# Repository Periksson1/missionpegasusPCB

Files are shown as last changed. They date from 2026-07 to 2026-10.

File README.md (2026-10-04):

# Mission Pegasus

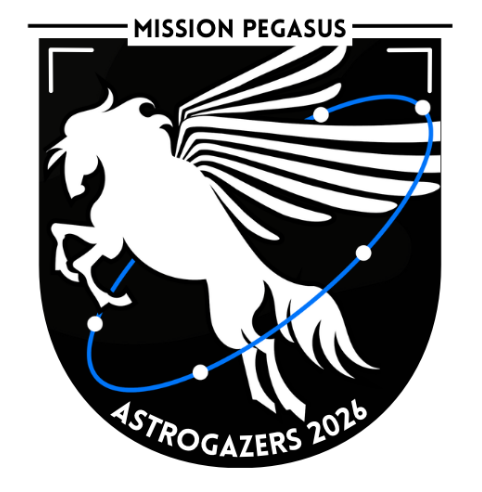
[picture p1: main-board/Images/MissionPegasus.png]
Mission Pegasus — Astrogazers 2026


PCB and mechanical design files for Mission Pegasus: a Raspberry Pi Zero carrier
and an AMS AS7265x spectral sensor board, designed to mate at 90°. The repository
includes schematics, PCB layouts, custom component libraries, mechanical CAD,
modal-analysis project files, and bills of materials.

## PDF schematics

Browse the current schematics without installing KiCad:

- [Main-board schematic (PDF)](output/pdf/main-board-schematic.pdf) - Raspberry Pi, stack interface, programming, and sensor connectors.
- [Sensor-board schematic (PDF)](output/pdf/sensor-board-schematic.pdf) - AS7265x sensors, flash, and board connector.

These are vector PDF exports of the current board schematics. Zoom in for pin
labels and component values. Regenerate the PDFs whenever the source schematics change.

## 3D CAD previews

These views are rendered from the KiCad PCB files and their associated 3D models.

### Main board

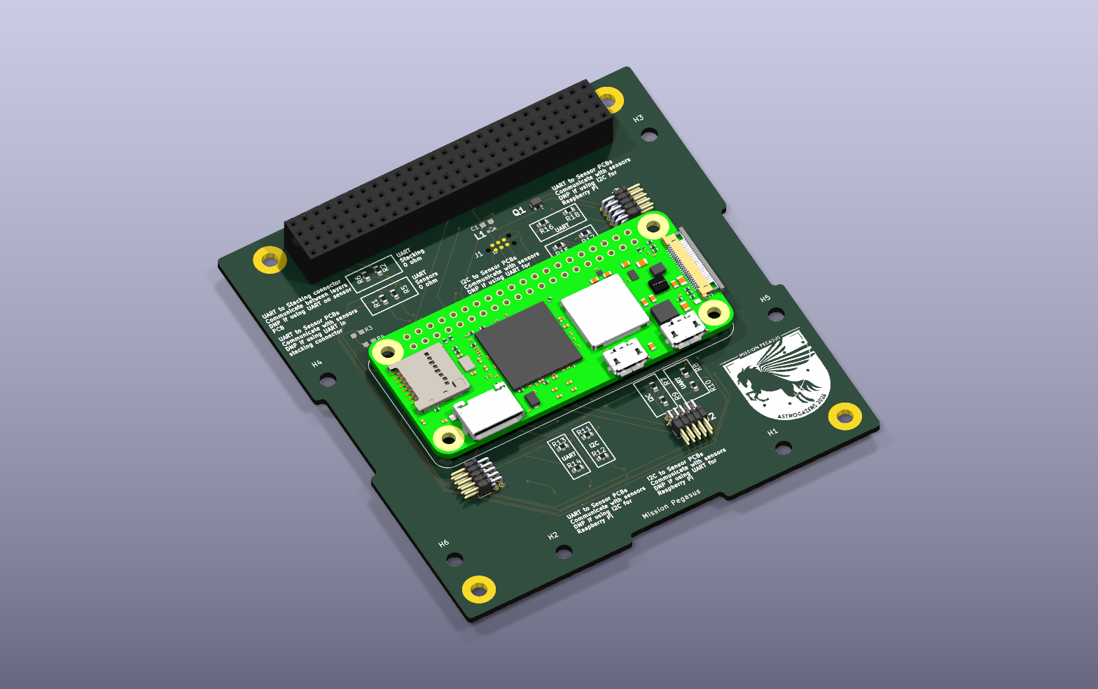
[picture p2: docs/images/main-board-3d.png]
Main-board 3D CAD view with Raspberry Pi Zero and stack connector


[Open the main-board project](main-board/Mission%20Pegasus.kicad_pro).

### Sensor board

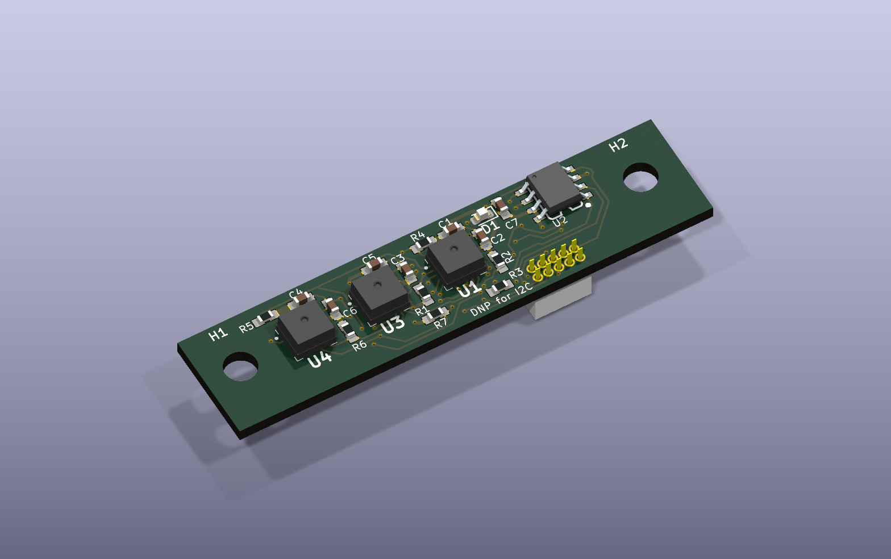
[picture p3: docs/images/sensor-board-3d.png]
Sensor-board 3D CAD view showing the spectral sensor components


[Open the sensor-board project](mezzanine-board/sensorPCB.kicad_pro).
For the mechanical assembly, see the [STEP export](CAD/PCBAssemblyFEA.stp)
and [Inventor CAD files](CAD/).

## Current design and status

The current design is on **[`main`](https://github.com/Periksson1/missionpegasusPCB/tree/main)**.
This is the default branch shown when you open the repository on GitHub.

Both boards have KiCad schematics and PCB layouts. CAD assemblies and an ANSYS
modal-analysis project are included. Manufacturing, assembly, electrical test,
and analysis pass/fail results are **not documented here yet**; the presence of
these files does not establish that the hardware has been validated.

## Getting started

1. Install **KiCad 10.0 or newer**. Both PCB files were saved with KiCad 10.0.
2. Clone the current design:

   ```sh
   git clone --branch main https://github.com/Periksson1/missionpegasusPCB.git
   cd missionpegasusPCB
   ```

3. Open `main-board/Mission Pegasus.kicad_pro` or
   `mezzanine-board/sensorPCB.kicad_pro` in KiCad's project manager.
4. Keep the project folders and their `libraries/` directories together. Custom
   library tables use `${KIPRJMOD}` paths; standard KiCad libraries are also needed.

For mechanical work, `.iam` and `.ipt` files are Autodesk Inventor assemblies and
parts. STEP (`.step` / `.stp`) exports are supplied for compatible CAD viewers.
`Analysis/ModalAnalysis.wbpj` is an ANSYS Workbench project; retain its adjacent
`ModalAnalysis_files/` directory. Exact Inventor and ANSYS application requirements
have not been documented.

## Boards

| Project | Description | Documentation |
|---|---|---|
| [Main board](main-board/Mission%20Pegasus.kicad_pro) | Raspberry Pi Zero carrier and stack interface | [Main-board README](main-board/README.md) |
| [Mezzanine board](mezzanine-board/sensorPCB.kicad_pro) | Spectral sensor daughterboard for the perpendicular assembly | [Mezzanine README](mezzanine-board/README.md) |

## Repository layout

| Path | Contents |
|---|---|
| `main-board/` | Main-board KiCad project, local libraries, documentation, BOMs, and CAD exports |
| `mezzanine-board/` | Sensor-board KiCad project, local libraries, BOMs, and CAD exports |
| `CAD/` | Mechanical assemblies, bracket parts, and assembly STEP export |
| `Analysis/` | ANSYS Workbench modal-analysis project and supporting files |
| `Combined BOM.xlsx` | Combined bill of materials |
| `Peter's Files/` | Additional copies of board projects, CAD, BOMs, and vendor software; use the top-level board folders for the documented workflow |
| `vendor/` | Third-party AMS dashboard software, firmware, and FTDI driver files |
| `MEZZANINE_INTERFACE.md` | Draft connector/interface planning notes with incomplete pin assignments |

The relationship and revision differences between `Peter's Files/` and the
top-level projects have not been reconciled in this documentation.

## BOMs and design references

- [Combined BOM](Combined%20BOM.xlsx)
- [Main-board BOM](main-board/Mission%20PegasusBOM.csv)
- [Sensor-board BOM](mezzanine-board/sensorPCBBOM.csv)
- [Component notes](main-board/docs/Components.docx) and [datasheets](main-board/docs/datasheets/)
- [Stack-interface schematic](main-board/StackInterface.kicad_sch)
- [Draft mezzanine interface](MEZZANINE_INTERFACE.md)
- [Mechanical assembly STEP export](CAD/PCBAssemblyFEA.stp)

BOMs and CAD exports are saved snapshots. Check them against the chosen board
revision before ordering parts or manufacturing. The interface document still
contains `TBD` pins; use the current schematics and verify connector numbering
and mechanical orientation before connecting hardware.

## Editing the designs

The main-board schematic contains cached versions of `AS72652`, `AS72653`, and
`RASPBERRY_PI_ZERO_2_W`. As noted in the [main-board documentation](main-board/README.md),
the corresponding library copies are older/incomplete. **Do not run
Tools → Update Symbols from Library on these parts** without first reconciling
the library definitions with the schematic.

When preparing a hardware revision, record its ERC/DRC results, fabrication
revision, assembly status, and test results alongside the design so readers can
distinguish design work from validated hardware.

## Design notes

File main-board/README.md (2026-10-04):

# Mission Pegasus main board

KiCad design for the Raspberry Pi Zero carrier and stack interface in the
Mission Pegasus two-board assembly.

[View the schematic PDF](../output/pdf/main-board-schematic.pdf).

## Opening the project

Use **KiCad 10.0 or newer** and open
[`Mission Pegasus.kicad_pro`](Mission%20Pegasus.kicad_pro).
See the [root README](../README.md) for cloning the current `main` branch.

## Files and references

| Path | Purpose |
|---|---|
| `Mission Pegasus.kicad_pro` | KiCad project settings |
| `Mission Pegasus.kicad_sch` | Root schematic |
| `Mission Pegasus.kicad_pcb` | PCB layout |
| `RPI0.kicad_sch` | Raspberry Pi Zero schematic sub-sheet |
| `StackInterface.kicad_sch` | Stack/GPIO interface sub-sheet |
| `fp-lib-table`, `sym-lib-table` | Project-local library registrations |
| `libraries/` | Custom footprints, symbols, and 3D models |
| `docs/` | Datasheets, component notes, ordering paperwork, and reference block diagram |
| `Mission PegasusBOM.csv` | Saved board BOM |
| `Images/` | Project artwork |
| `mainboard*.step`, `mainboard6/` | Mechanical exports and CAD files |

Custom library tables use `${KIPRJMOD}` paths. Keep the libraries with the
project and install the standard KiCad libraries. Third-party dashboard software,
firmware, and drivers are in [`../vendor/`](../vendor/).

## Interface and status

See the [stack schematic](StackInterface.kicad_sch) and
[draft mezzanine interface notes](../MEZZANINE_INTERFACE.md). The notes still have
incomplete pin assignments and must be checked against the current schematics.

Schematic and PCB design files are present. Manufacturing and electrical test
results are not documented. Check the [BOM](Mission%20PegasusBOM.csv) and mechanical
exports against the selected revision before using them for fabrication.

## Note on library symbols

The symbols cached in the schematics (`AS72652`, `AS72653`, and
`RASPBERRY_PI_ZERO_2_W`) are the authoritative, complete versions described by this
project's existing documentation. The library copies are older/incomplete.
**Do not run Tools → Update Symbols from Library on these parts** without first
reconciling the definitions; replacing them can break connectivity.

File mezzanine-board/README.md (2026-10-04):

# Mission Pegasus mezzanine sensor board

Spectral sensor daughterboard for the perpendicular Mission Pegasus assembly.
The KiCad project already contains a schematic and PCB layout.

[View the schematic PDF](../output/pdf/sensor-board-schematic.pdf).

## Opening the project

Use **KiCad 10.0 or newer** and open [`sensorPCB.kicad_pro`](sensorPCB.kicad_pro).
See the [root README](../README.md) for cloning the current `main` branch.
Keep the project's `libraries/` directory alongside the design files; custom
library registrations use `${KIPRJMOD}` paths. Standard KiCad libraries are also
needed.

## Files and references

| Path | Purpose |
|---|---|
| `sensorPCB.kicad_pro` | KiCad project settings |
| `sensorPCB.kicad_sch` | Sensor-board schematic |
| `sensorPCB.kicad_pcb` | Sensor-board PCB layout |
| `fp-lib-table`, `sym-lib-table` | Custom library registrations |
| `libraries/` | Custom symbols, footprints, and 3D models |
| `sensorPCBBOM.csv` | Saved sensor-board BOM |
| `sensorboard*.step` | Mechanical exports |
| `sensorboard2/`, `sensorboard3/`, `sensorboard5/` | CAD parts and assemblies |

## Mating interface

Review the [main-board stack schematic](../main-board/StackInterface.kicad_sch)
and both current board schematics when checking the connector pinout. The
[draft interface notes](../MEZZANINE_INTERFACE.md) contain incomplete assignments;
they are not a verified wiring specification.

Confirm pin-1 orientation, matching signal assignments, connector placement,
and clearance in the perpendicular assembly. Assembly CAD is in
[`../CAD/`](../CAD/).

## Design status

Schematic, PCB, BOM, and mechanical files are present. Manufacturing, assembly,
and electrical test results are not documented. The [BOM](sensorPCBBOM.csv) and
CAD exports should be checked against the chosen PCB revision before use.

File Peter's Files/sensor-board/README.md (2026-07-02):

# Mezzanine board (90°)

Daughterboard that mates **perpendicular** to the Mission Pegasus main board
via the shared 2x26 (2.54 mm) stack connector.

> Status: not started — create the KiCad project into this folder (see below).

## Creating the project

1. In KiCad: **File → New Project…**
2. Save it **inside this `mezzanine-board/` folder** (e.g. `Mezzanine.kicad_pro`).
   Keep "Create a new folder" **unchecked** so the files land here directly.
3. Custom parts go in the pre-made `libraries/` subfolders:
   - `libraries/footprints/` (`.pretty`)
   - `libraries/symbols/` (`.kicad_sym`)
   - `libraries/3dmodels/` (`.3dshapes`)
   Register them in this project's `fp-lib-table` / `sym-lib-table` using
   `${KIPRJMOD}/libraries/...` paths so the board stays self-contained.

## The 90° mating interface

- Use the **same connector part and pinout** as the main board's stack
  interface (see `../main-board/StackInterface.kicad_sch`). Pin 1 must meet
  pin 1.
- For the right-angle mate, typically one board carries a **right-angle**
  header and the other a vertical socket. Decide which side is which.
- Match the **connector position and board outline** so the boards align
  physically. Verify by exporting STEP from both boards and checking the
  perpendicular fit in a 3D view.

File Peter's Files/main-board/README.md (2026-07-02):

# Mission Pegasus PCB

KiCad design for the Mission Pegasus board — a Raspberry Pi Zero based
carrier with an AMS AS7265x spectral sensor front end.

## Opening the project

Open `Mission Pegasus.kicad_pro` in KiCad (10.0 or newer).

## Layout

```
Mission Pegasus.kicad_pro / .sch / .pcb   Main project (open this)
RPI0.kicad_sch                            Sub-sheet: Raspberry Pi Zero
StackInterface.kicad_sch                  Sub-sheet: stack / GPIO interface
fp-lib-table, sym-lib-table               Project-local library registrations

libraries/                                All custom parts libraries
├── footprints/   *.pretty                Footprint libraries
├── symbols/      *.kicad_sym             Symbol libraries
└── 3dmodels/     *.3dshapes              3D models (STEP)

docs/                                     Documentation & manufacturing
├── datasheets/                           AS7265x datasheets / app notes
├── Components.docx                       Component notes
├── Mission Pegasus.csv                   BOM
├── Order Request form.xlsx              Ordering paperwork
└── block_diagram.kicad_sch              Reference block diagram (not in build)

vendor/                                   Third-party tooling (reference only)
└── AS7265x DashBoard Software/           AMS dashboard app, firmware, FTDI driver
```

All library and 3D-model paths are project-relative (`${KIPRJMOD}`), so the
repo is self-contained — clone it anywhere and it opens without missing files.

## Note on library symbols

The symbols cached in the schematics (AS72652 / AS72653 / RASPBERRY_PI_ZERO_2_W)
are the authoritative, complete versions and match the PCB. The library copies
are older/incomplete. **Do not run _Tools → Update Symbols from Library_** on
these parts — it would pull the incomplete library version into the schematic
and break connectivity.

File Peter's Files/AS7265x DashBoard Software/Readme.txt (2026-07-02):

For AS7265x 

This folder consist of

          - FTDI Virtual COM Port Driver Setup exe file 
          - Dashboard Software - tcl Dashboard Installation file (DashBoard software AS7265x)
          - current AS7265 firmware - Complete 256kb and Update 56kb firmware bin file and AT-command list xlsx file

Note: - PC and Winbdws 32/64 Bit
              ActiveState TCL Run-Time Setup - TCL run time exe file for windows 32 or 64 bit (download from ActiveState TCL site) to run the Dashboard Software 

The AS7265x test system is tightly integrated with its companion firmware, which allows periodic enhancements and updates. Please download the latest version of the datasheet, which includes the current command set and features on the Spectral Sensing Product family page at https://ams.com/upload-center.
Also download User Guide.

User will have to create an account on ams.com (click login -> Create Account) to request the download SW data and relevent documents 

Please read forUser Guide in the documentation set. Then connect the hardware based on our instructions in User Guide  and run the test software.

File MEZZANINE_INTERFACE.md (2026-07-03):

# Mezzanine 90° Interface Specification

The single source of truth for the connector shared between the **main board**
and the **90° mezzanine board**. Edit this first; then make both boards match it.

## Connector

| Property | Value |
|---|---|
| Type | 2×20, 2.54 mm pitch, 40 positions |
| Mezzanine side | Molex **90152-2140** right-angle receptacle (makes the mezzanine stand vertical) |
| Main board side | Vertical 2×20 pin header (KiCad `Connector_PinHeader_2.54mm:PinHeader_2x20_P2.54mm_Vertical`) |
| Locations on main board | **3**, all populated, wired **in parallel** to the same nets (plug the mezzanine into any one) |
| Constraint | Only **one** mezzanine plugged at a time (parallel positions share nets) |

> Pin 1 on the main-board header must meet pin 1 on the mezzanine receptacle.
> Confirm the receptacle's pin-1 location and numbering direction against the
> Molex datasheet before finalizing the footprint.

## Pin assignment (fill this in)

Signals are TBD — assign from the "available signals" menu below based on what
the mezzanine needs. Power/ground pins are pre-suggested for signal integrity
(GND on corners + middle; keep power and its return adjacent).

| Pin | Signal | | Pin | Signal |
|----:|---|-|----:|---|
| 1 | GND *(key/orientation)* | | 2 | 5V_PERM |
| 3 | TBD | | 4 | 5V_PERM |
| 5 | TBD | | 6 | GND |
| 7 | TBD | | 8 | TBD |
| 9 | TBD | | 10 | TBD |
| 11 | TBD | | 12 | TBD |
| 13 | TBD | | 14 | TBD |
| 15 | TBD | | 16 | TBD |
| 17 | TBD | | 18 | TBD |
| 19 | TBD | | 20 | GND |
| 21 | GND | | 22 | TBD |
| 23 | TBD | | 24 | TBD |
| 25 | TBD | | 26 | TBD |
| 27 | TBD | | 28 | TBD |
| 29 | TBD | | 30 | TBD |
| 31 | TBD | | 32 | TBD |
| 33 | TBD | | 34 | TBD |
| 35 | TBD | | 36 | GND |
| 37 | TBD | | 38 | BATT |
| 39 | GND | | 40 | BATT |

## Available signals (from the main board stack, for reference)

Buses / signals present on the main board that the mezzanine could tap:

- **Power**: `5V_PERM`, `BATT`, `CHARGE`, `PWR_1`…`PWR_20` (each with an `ENA_PWR_n` enable)
- **CAN**: `CAN_A_H` / `CAN_A_L`, `CAN_B_H` / `CAN_B_L`
- **UART**: `UART_A_UP`/`UART_A_DN` … `UART_F_UP`/`UART_F_DN`
- **Deploy / RBF**: `RBF_A`, `RBF_B`, `DS_A`, `DS_B`
- **Ground**: `GND`

Full extracted stack pinout is in the git history of `main-board/` (netlist);
regenerate anytime with:
`kicad-cli sch export netlist --format kicadxml "main-board/Mission Pegasus.kicad_sch"`

## Build order

1. **This file** — lock the 40-pin assignment.
2. **Main board** — add 3× `PinHeader_2x20_P2.54mm_Vertical`, wire all three in
   parallel to the assigned nets, add mounting holes at each location.
3. **Mezzanine board** — place the Molex right-angle receptacle with the same
   pinout, design the board outline, add matching mounting holes.
4. **Mechanical check** — export STEP from both boards, confirm the perpendicular
   fit and that the 3 positions don't collide with other components.

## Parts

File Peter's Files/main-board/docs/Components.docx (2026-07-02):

Spectral sensors

AS72651-BLGT

https://www.mouser.co.uk/ProductDetail/ams-OSRAM/AS72651-BLGT?qs=YCa%2FAAYMW03SsE5ip4GyWw%3D%3D

AS72652-BLGM

https://www.mouser.co.uk/ProductDetail/ams-OSRAM/AS72652-BLGM?qs=byeeYqUIh0MwQKd6yzDQEA%3D%3D

AS72653-BLGM

https://www.mouser.co.uk/ProductDetail/ams-OSRAM/AS72653-BLGM?qs=byeeYqUIh0N5Q0CaJCwXCA%3D%3D

4MB Flash

https://www.mouser.co.uk/c/?q=AT25SF041

Diagram

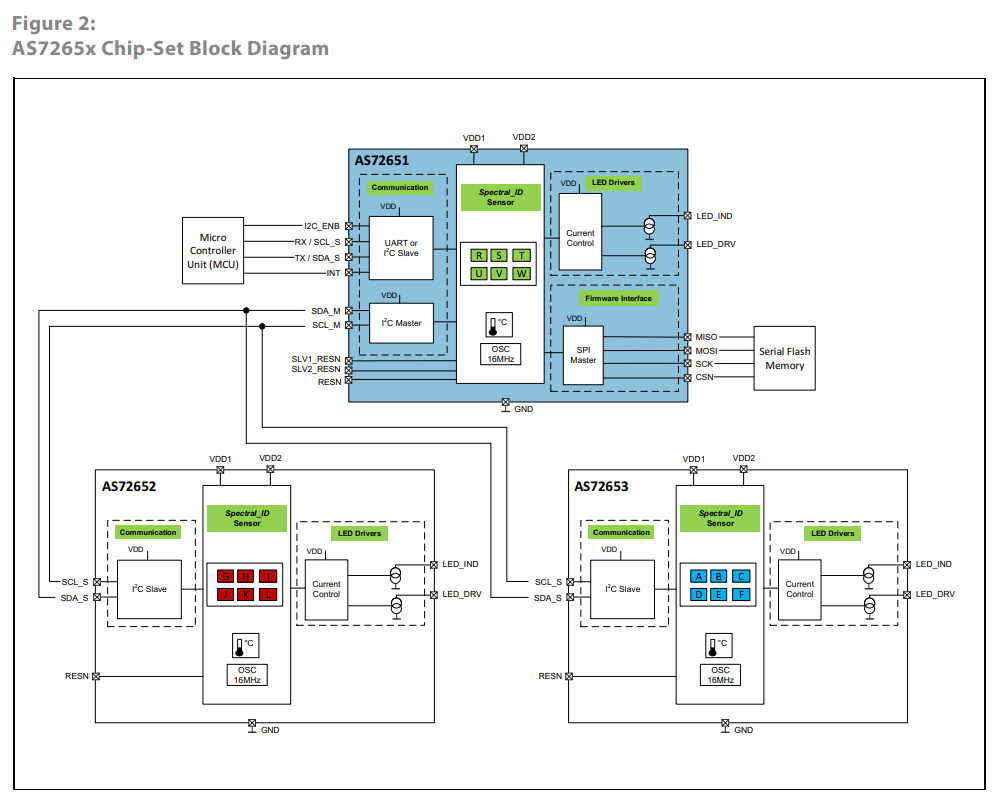
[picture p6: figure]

Design considerations

The AS72651 device needs a flash memory to store the firmware and the data. The flash memory should be at least 2-Mbits operating at SPI mode 0 with byte write supported.

The LED, D11 in the typical schematic, is recommended for debugging purpose. During AS72651 power up, D11 should be on for a short time and off. If D11 is blinking, it indicates there is an issue with accessing the flash memory content.

Schematic

file:///C:/Users/User/OneDrive%20-%20University%20of%20Bath/Mission%20Pegasus/Sparkfun/AS7265x%20Schematic%20Generation_2.pdf

Firmware

Connectors

PC104 layers

Samtec ESQ-126-39-G-D

https://www.mouser.co.uk/ProductDetail/Samtec/ESQ-126-39-G-D?qs=Cqqh%252BS766wm7W672HSOlSA%3D%3D

Raspberry pi to main board

https://www.mouser.co.uk/ProductDetail/SchmartBoard/920-0135-01?qs=WBUF01kN13lvFiBwxduHPw%3D%3D

Spark fun Github

https://github.com/sparkfun/Qwiic_Spectral_Sensor_AS7265x

Questions

VDD1 VDD1

INT and RST help, why not on the qwik connect

All on one board?

No LEDs

RST ADDR

Trust schematic or datasheet

Get MOUSR numbers for 10 boards

Sensors on opposite sides

Pi zero, boards

Farnell

Raspberry Pis in space

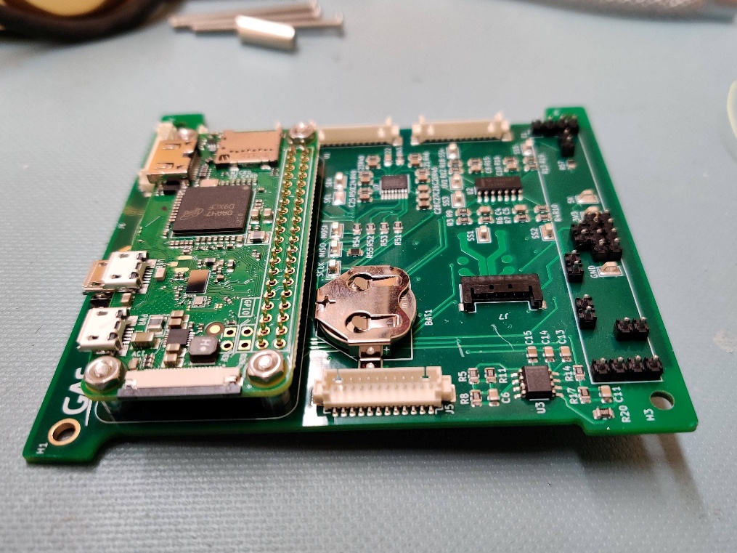
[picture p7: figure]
GASPACS Electrical Board

https://nepp.nasa.gov/docs/papers/2021-Guertin-Raspberry-Pi-Guideline-CL-21-5641.pdf

Watchdog

DFRobot Beetle Board

Software

https://github.com/SmallSatGasTeam/CubeWorks

2 x20 pins connection

https://thepihut.com/products/break-away-0-1-2x20-pin-strip-dual-male-header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

https://www.mouser.co.uk/ProductDetail/SchmartBoard/920-0199-01?qs=5aG0NVq1C4wO2QQoWinwcA%3D%3D

Board to board

https://www.mouser.co.uk/ProductDetail/Amphenol-FCI/68021-120HLF?qs=QKvFUfBIyQLKTXbLGClQCQ%3D%3D

https://www.mouser.co.uk/ProductDetail/Molex/10-88-3201?qs=yq6dHiFsY%2FwBE5jk1c6zoQ%3D%3D

PCB Receptacle, Board-to-Board, 2.54 mm, 2 Rows, 40 Contacts, Female Receptacle

https://uk.farnell.com/molex/90152-2140/conn-r-a-rcpt-40pos-2row-2-54mm/dp/3865288

https://www.mouser.co.uk/ProductDetail/Molex/503376-4010?qs=6kT3pPPHxnUcJRrksBOx%2Fg%3D%3D

https://www.mouser.co.uk/ProductDetail/Molex/70247-4051?qs=L7RdmAxh%252BcMhqlOlB5RHog%3D%3D

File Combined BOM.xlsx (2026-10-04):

Mission Pegasus BOM
Sensor PCB
Reference | Catalogue Number | Qty | Value | Description | Unit Price | Supplier | Link | Footprint | Datasheet
C1,C3,C4 | 581-0603YC104K4T4A | 3 | 100nF | Capacitor | 0.027 |  | https://www.mouser.co.uk/ProductDetail/KYOCERA-AVX/0603YC104K4T4A?qs=Cej1j9ztgjEkPqVJkA4Bng%3D%3D | SparkfunLibrary:0603
C2,C5,C6 | 06033D105KAT4A | 3 | 1 uF | Capacitor | 0.074 |  | https://www.mouser.co.uk/ProductDetail/KYOCERA-AVX/06033D105KAT4A | SparkfunLibrary:0603
C7 | 06033D105KAT4A | 1 | 1uF | Capacitor | 0.074 |  | https://www.mouser.co.uk/ProductDetail/KYOCERA-AVX/06033D105KAT4A | SparkfunLibrary:0603
D1 | 327-FR1101C2005MTR | 1 | GREEN | LED | £0.18 | Mouser | https://www.mouser.co.uk/en/ProductDetail/Stanley-Electric/FR1101C-2005-M-TR | LED_SMD:LED_0603_1608Metric
J1 | 200-SFMC10501LD | 1 | SFMC-105-01-L-D | 10 pin header | £1.58 | Mouser | https://www.mouser.co.uk/en/ProductDetail/Samtec/SFMC-105-01-L-D?qs=PB6%2FjmICvI2ISwddtR74VA%3D%3D | SamacSys_Parts:SFMC-105-XX-YY-D | http://suddendocs.samtec.com/prints/sfmc-1xx-xx-xx-d-xx-mkt.pdf
R1,R2,R4,R5 | 71-CRCW060310K0FKEI | 4 | 10k | 10 k ohm resistor | 0.047 | Mouser | https://www.mouser.co.uk/ProductDetail/Vishay/CRCW060310K0FKEI?qs=3qWEzBg5KnKofE%252B8acPBRA%3D%3D | SparkfunLibrary:0603
R3 | 603-RC0603FR-100RL | 1 | 0R | 0 ohm resistors | £0.01 | Mouser | https://www.mouser.co.uk/en/ProductDetail/YAGEO/RC0603FR-100RL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 | SparkfunLibrary:0603
R6,R7 | 71-CRCW0603-2.2K-E3 | 2 | 2.2k | 2.2 k Ohm resistor | 0.015 | Mouser | https://www.mouser.co.uk/en/ProductDetail/Vishay/CRCW06032K20FKEA?qs=wckIcdUuIXiMEbhHncbunA%3D%3D | SparkfunLibrary:0603
U1 | 985-AS72651-BLGM | 1 | AS72651 | Sensor | 7.23 | Mouser | https://www.mouser.co.uk/ProductDetail/ams-OSRAM/AS72651-BLGM?qs=byeeYqUIh0PtfXPN2yhDCA%3D%3D | SamacSys_Parts:AS72651BLGT | https://ams.com/documents/20143/36005/AS7265x_DS000612_1-00.pdf/08051c8a-a7f6-6231-7993-2d3fe0bf38b8
U2 | 988-AT25SF041BSSHDB | 1 | 4MB Flash | 4mb Flash | £0.48 | Mouser | https://www.mouser.co.uk/en/ProductDetail/Renesas-Dialog/AT25SF041B-SSHD-B?qs=IS%252B4QmGtzzoAv7Cb4U2tFA%3D%3D | SparkfunLibrary:4MbFlash
U3 | 985-AS72652-BLGM | 1 | AS72652 | Sensor | 7.23 | Mouser | https://www.mouser.co.uk/ProductDetail/ams-OSRAM/AS72652-BLGM?qs=byeeYqUIh0MwQKd6yzDQEA%3D%3D | SamacSys_Parts:AS72651BLGT
U4 | 985-AS72653-BLGM | 1 | AS72653 | Sensor | 7.23 | Mouser | https://www.mouser.co.uk/ProductDetail/ams-OSRAM/AS72653-BLGM?qs=byeeYqUIh0N5Q0CaJCwXCA%3D%3D | SamacSys_Parts:AS72651BLGT
Main Board
Reference | Catalogue Number | Qty | Value |  |  |  |  | Footprint | Datasheet
C1 | 581-0603YC104K4T4A | 1 | 100nF | Capacitor | 0.027 |  | https://www.mouser.co.uk/ProductDetail/KYOCERA-AVX/0603YC104K4T4A?qs=Cej1j9ztgjEkPqVJkA4Bng%3D%3D | SparkfunLibrary:0603
H7,H8 | 06033D105KAT4A | 2 | PC/104 Connector |  |  |  |  | Connector_PinSocket_2.54mm:PinSocket_2x26_P2.54mm_Vertical
J2,J3,J4 | FTSH-105-04-L-D-RA | 3 | FTSH-105-04-L-D-RA | Right angle connector | £1.44 | Digikey | https://www.digikey.co.uk/en/products/detail/samtec-inc/FTSH-105-04-L-D-RA/6678181 | SamacSys_Parts:FTSH-105-XX-YYY-D-RA | http://suddendocs.samtec.com/prints/ftsh-1xx-xx-xxx-dv-xxx-xxx-mkt.pdf
L1 | 710-7427927161 | 1 | 60R/250mA | Ferrite beads | 0.137 | Mouser | https://www.mouser.co.uk/en/ProductDetail/Wurth-Elektronik/7427927161?qs=%252B97ACBfLqz8R%252B1ZKS2FUPA%3D%3D | SamacSys_Parts:0402
Q1 | 755-DTC113ZEBTL | 1 | DTC113Z | Transistor | 0.107 | Mouser | https://www.mouser.co.uk/ProductDetail/ROHM-Semiconductor/DTC113ZEBTL?qs=qSfuJ%252Bfl%2Fd4AkBOHinnQ0A%3D%3D | SamacSys_Parts:DTC113ZUA
R1,R2,R5,R6,R7,R8,R9,R10,R11,R12,R13,R14,R15,R16,R17,R18 | 603-RC0603FR-100RL | 16 | 0R | 0 ohm resistors | £0.01 | Mouser | https://www.mouser.co.uk/en/ProductDetail/YAGEO/RC0603FR-100RL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 | Resistor_SMD:R_0603_1608Metric
R3,R4 | 71-CRCW0603-2.2K-E3 | 2 | 2.2k | 2.2 k Ohm resistor | 0.015 | Mouser | https://www.mouser.co.uk/en/ProductDetail/Vishay/CRCW06032K20FKEA?qs=wckIcdUuIXiMEbhHncbunA%3D%3D | SparkfunLibrary:0603
U1 |  | 1 | RASPBERRY_PI_ZERO_2_W |  |  |  |  | RPIZERO:RASPBERRYPI-ZERO_RPI-ZERO
Mounting
Catalogue Number | Qty | Description | Supplier | Link
36-615-ND | 2 | Angle bracket | Digikey | https://www.digikey.co.uk/en/products/detail/keystone-electronics/615/316537
855-R25-3000302 | 4 | Standoffs | Mouser | https://www.mouser.co.uk/en/ProductDetail/Harwin/R25-3000302?qs=vF78I%252BjhbY82jhRkZ%252BKjhQ%3D%3D
485-2222 | 1 | GPIO 2x20 Female Header 2.54mm pitch | Mouser | https://www.mouser.co.uk/en/ProductDetail/Adafruit/2222?qs=GURawfaeGuDZD0rNtWpsaQ%3D%3D
Flash
Catalogue Number | Qty | Description | Supplier | Link
TC2030-IDC-NL | 1 | Flash connector | Tag-Connect | https://www.tag-connect.com/product/tc2030-idc-nl

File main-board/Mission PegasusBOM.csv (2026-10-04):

Reference | Qty | Value | DNP | Exclude from BOM | Exclude from Board | Footprint | Datasheet | MANUFACTURER | Price
C1 | 1 | 100nF |  |  |  | SparkfunLibrary:0603
H7,H8 | 2 | PC/104 Connector |  |  |  | Connector_PinSocket_2.54mm:PinSocket_2x26_P2.54mm_Vertical
J2,J3,J4 | 3 | FTSH-105-04-L-D-RA |  |  |  | SamacSys_Parts:FTSH-105-XX-YYY-D-RA | http://suddendocs.samtec.com/prints/ftsh-1xx-xx-xxx-dv-xxx-xxx-mkt.pdf
L1 | 1 | 60R/250mA |  |  |  | SamacSys_Parts:0402
Q1 | 1 | DTC113Z |  |  |  | SamacSys_Parts:DTC113ZUA
R1,R2,R5,R6,R7,R8,R9,R10,R11,R12,R13,R14,R15,R16,R17,R18 | 16 | 0R |  |  |  | Resistor_SMD:R_0603_1608Metric
R3,R4 | 2 | 2.2k |  |  |  | SparkfunLibrary:0603
U1 | 1 | RASPBERRY_PI_ZERO_2_W |  |  |  | RPIZERO:RASPBERRYPI-ZERO_RPI-ZERO |  | Raspberry Pi | None

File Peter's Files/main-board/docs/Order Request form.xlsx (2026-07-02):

ORDER REQUEST FORM
To: | Finance |  |  |  | Requisition Number
From: |  |  |  |  | PO Number
Department:
Supplier Name: |  |  |  | Project Code:
Supplier Address: |  |  |  |  | Type of Purchase | Please indicate
 |  |  |  |  | Lab Equipment
 |  |  |  |  | Lab consumables
Telephone: |  |  |  |  | IT
Email: |  |  |  |  | Other
Quote number:
PLEASE SEND COMPLETED FORM TO fac-eng-finance@bath.ac.uk
 | Quantity | Catalogue Number | Description of Goods |  |  | Unit Price | Total Price | Supplier | Link
1 | 1 | TC2030-IDC-NL | Debugging Connector |  |  | £26.46 | 26.46 | Tag-Connect | https://www.tag-connect.com/product/tc2030-idc-nl
2 | 10 | 985-AS72651-BLGM | Sensor |  |  | 7.23 | 72.3 | Mouser | https://www.mouser.co.uk/ProductDetail/ams-OSRAM/AS72651-BLGM?qs=byeeYqUIh0PtfXPN2yhDCA%3D%3D
3 | 10 | 985-AS72652-BLGM | Sensor |  |  | 7.23 | 72.3 | Mouser | https://www.mouser.co.uk/ProductDetail/ams-OSRAM/AS72652-BLGM?qs=byeeYqUIh0MwQKd6yzDQEA%3D%3D
4 | 10 | 985-AS72653-BLGM | Sensor |  |  | 7.23 | 72.3 | Mouser | https://www.mouser.co.uk/ProductDetail/ams-OSRAM/AS72653-BLGM?qs=byeeYqUIh0N5Q0CaJCwXCA%3D%3D
5 | 60 | 581-0603YC104K4T4A | 0.1 uF Capacitor |  |  | 0.027 | 1.62 | Mouser | https://www.mouser.co.uk/ProductDetail/KYOCERA-AVX/0603YC104K4T4A?qs=Cej1j9ztgjEkPqVJkA4Bng%3D%3D
6 | 60 | 581-06033D105KAT4A | 1 uF Capacitor |  |  | 0.074 | 4.44 | Mouser | https://www.mouser.co.uk/ProductDetail/KYOCERA-AVX/06033D105KAT4A
7 | 10 | 710-7427927161 | Ferrite beads |  |  | 0.137 | 1.37 | Mouser | https://www.mouser.co.uk/ProductDetail/Wurth-Elektronik/7427927161?qs=%252B97ACBfLqz8R%252B1ZKS2FUPA%3D%3D
8 | 10 | 755-DTC113ZEBTL | Transistor |  |  | 0.107 | 1.07 | Mouser | https://www.mouser.co.uk/ProductDetail/ROHM-Semiconductor/DTC113ZEBTL?qs=qSfuJ%252Bfl%2Fd4AkBOHinnQ0A%3D%3D
9 | 80 | 71-CRCW0603-2.2K-E3 | Resistor |  |  | 0.015 | 1.2 | Mouser | https://www.mouser.co.uk/ProductDetail/Vishay/CRCW06032K20FKEA?qs=wckIcdUuIXiMEbhHncbunA%3D%3D
10 | 60 | 71-CRCW060310K0FKEI | Resistor |  |  | 0.047 | 2.82 | Mouser | https://www.mouser.co.uk/ProductDetail/Vishay/CRCW060310K0FKEI?qs=3qWEzBg5KnKofE%252B8acPBRA%3D%3D
 |  |  |  |  |  | Delivery:
 |  |  |  |  |  | Subtotal: | 255.88
 |  |  |  |  |  | 20% VAT: | 51.18
 |  |  |  |  |  | Total: | 307.06
Additional Forms - Have you attached?
£2000-£9999 |  | 3 Competative quotes or 1 quote and justification for only seeking one
£10,000- £24,999 |  | BID Evaluation Document (BED) https://www.bath.ac.uk/publications/bid-evaluation-document/ or Single Action Waiver (SAW) https://www.bath.ac.uk/publications/single-action-waiver/
£25,000+ |  | Contact Procurement https://www.bath.ac.uk/teams/procurement-team/

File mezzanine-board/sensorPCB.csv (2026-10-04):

Reference | Qty | Value | DNP | Exclude from BOM | Exclude from Board | Footprint | Datasheet
C1,C3,C4 | 3 | 100nF |  |  |  | SparkfunLibrary:0603
C2,C5,C6 | 3 | 1 uF |  |  |  | SparkfunLibrary:0603
C7 | 1 | 1uF |  |  |  | SparkfunLibrary:0603
D1 | 1 | GREEN |  |  |  | LED_SMD:LED_0603_1608Metric
J1 | 1 | SFMC-105-01-L-D |  |  |  | SamacSys_Parts:SFMC-105-XX-YY-D | http://suddendocs.samtec.com/prints/sfmc-1xx-xx-xx-d-xx-mkt.pdf
R1,R2,R4,R5 | 4 | 10k |  |  |  | SparkfunLibrary:0603
R3 | 1 | 0R |  |  |  | SparkfunLibrary:0603
R6,R7 | 2 | 2k2 |  |  |  | SparkfunLibrary:0603
U1 | 1 | AS72651 |  |  |  | SamacSys_Parts:AS72651BLGT | https://ams.com/documents/20143/36005/AS7265x_DS000612_1-00.pdf/08051c8a-a7f6-6231-7993-2d3fe0bf38b8
U2 | 1 | 4MB Flash |  |  |  | SparkfunLibrary:4MbFlash
U3 | 1 | AS72652 |  |  |  | SamacSys_Parts:AS72651BLGT
U4 | 1 | AS72653 |  |  |  | SamacSys_Parts:AS72651BLGT

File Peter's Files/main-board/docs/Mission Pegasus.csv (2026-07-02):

Reference | Qty | Value | DNP | Exclude from BOM | Exclude from Board | Footprint | Datasheet | MANUFACTURER | Price
C1,C3,C5,C8 | 4 | 100nF |  |  |  | SparkfunLibrary:0603
C2,C4,C6 | 3 | 1 uF |  |  |  | SparkfunLibrary:0603
C7 | 1 | 1uF |  |  |  | SparkfunLibrary:0603
D1 | 1 | GREEN
H1,H2 | 2 | PC/104 Connector |  |  |  | Connector_PinSocket_2.54mm:PinSocket_2x26_P2.54mm_Vertical
L1 | 1 | 60R/250mA |  |  |  | SamacSys_Parts:0402
Q1 | 1 | DTC113Z |  |  |  | SamacSys_Parts:DTC113ZUA
R1,R2 | 2 | 2.2k |  |  |  | SparkfunLibrary:0603
R3,R6,R7,R8 | 4 | 10k |  |  |  | SparkfunLibrary:0603
R5 | 1 | 0R |  |  |  | SparkfunLibrary:0603
R9,R10 | 2 | 2k2 |  |  |  | SparkfunLibrary:0603
TP1,TP2,TP3 | 3 | TestPoint |  |  |  | TestPoint:TestPoint_Pad_D1.0mm
U2 | 1 | 4MB Flash |  |  |  | SparkfunLibrary:4MbFlash
U3 | 1 | AS72652 |  |  |  | SparkfunLibrary:AS72651
U4 | 1 | AS72653 |  |  |  | SparkfunLibrary:AS72651
U6 | 1 | AS72651 |  |  |  | Package_LGA:AMS_LGA-20_4.7x4.5mm_P0.65mm | https://ams.com/documents/20143/36005/AS7265x_DS000612_1-00.pdf/08051c8a-a7f6-6231-7993-2d3fe0bf38b8
U7 | 1 | RASPBERRY_PI_ZERO_2_W |  |  |  | RPIZERO:RASPBERRYPI-ZERO_RPI-ZERO |  | Raspberry Pi | None

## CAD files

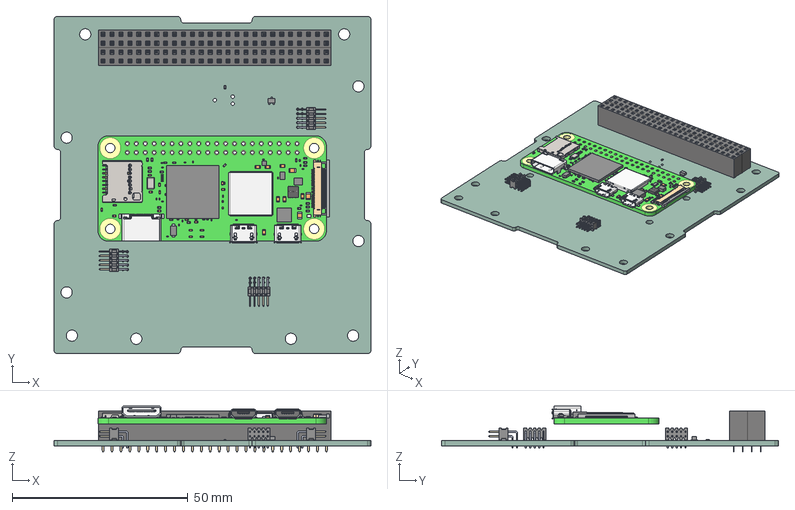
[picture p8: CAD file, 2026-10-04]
main-board/mainboard2.step
90.2 x 95.9 x 13.0 mm
Pins
PCB, Raspberry Pi Zero 2 W
RP3A0-AU 2105 201221C, Raspberry Pi Zero 2 W
MicroUSB Port, Raspberry Pi Zero 2 W x 2
SD Card Slot, Raspberry Pi Zero 2 W
Wireless Module Cover, Raspberry Pi Zero 2 W
Crystal Resonator, Raspberry Pi Zero 2 W
LED, Raspberry Pi Zero 2 W
Diode, Schottky, Raspberry Pi Zero 2 W
54548-2271, 22 Pin FPC Connector, Raspberry Pi Zero 2 W
Mini HDMI Receptacle Port, Raspberry Pi Zero 2 W
PAM2306AYPKE, Switching Voltage Regulators Dual PWM Step-Down 40uA 1A 1.5MHz, Raspberry Pi Zero 2 W
RT9081A-1BGQZA, Fixed LDO Voltage Regulator, 0.8V-5.5Vin, 140mV drop, 1.25Vout, 0.5Aout, Raspberry Pi Zero 2 W_default
RT8088AWSC, IC Reg Buck Prog 3A Sync 15WLCSP, Raspberry Pi Zero 2 W_default
SMD Inductor, Configurable, Raspberry Pi Zero 2 W_L1
SMD Inductor, Configurable, Raspberry Pi Zero 2 W_L2
SMD Capacitor, Configurable, Raspberry Pi Zero 2 W_C1 x 3
SMD Capacitor, Configurable, Raspberry Pi Zero 2 W_C3 x 7
SMD Capacitor, Configurable, Raspberry Pi Zero 2 W_C2 x 31
SMD Capacitor, Configurable, Raspberry Pi Zero 2 W_C10 x 15
SMD Resistor, Configurable, Raspberry Pi Zero 2 W_R1 x 20
SMD Resistor, Configurable, Raspberry Pi Zero 2 W_R12
Lötende x 2
PinSocket_2x26_P2.54mm_Vertical x 2
Mission Pegasus_PCB

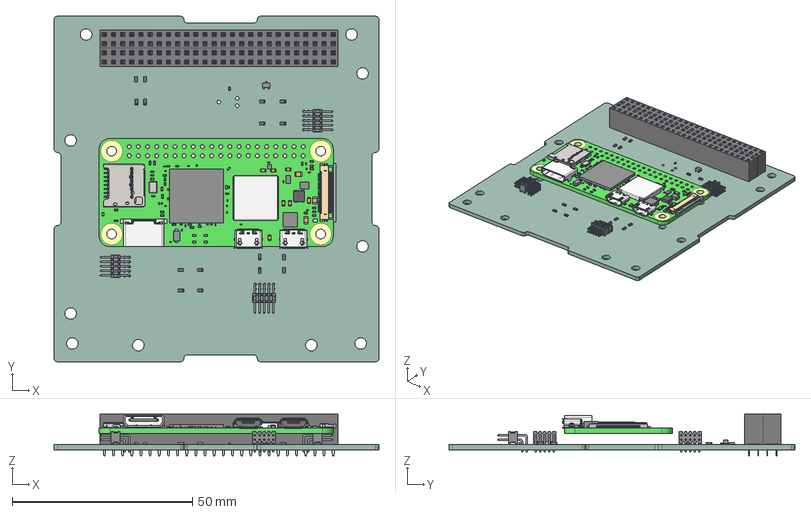
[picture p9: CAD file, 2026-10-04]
Peter's Files/main-board/mainboardCAD/mainboard6.step
90.2 x 95.9 x 11.6 mm
R_0603_1608Metric x 16
Pins
PCB, Raspberry Pi Zero 2 W
RP3A0-AU 2105 201221C, Raspberry Pi Zero 2 W
MicroUSB Port, Raspberry Pi Zero 2 W x 2
SD Card Slot, Raspberry Pi Zero 2 W
Wireless Module Cover, Raspberry Pi Zero 2 W
Crystal Resonator, Raspberry Pi Zero 2 W
LED, Raspberry Pi Zero 2 W
Diode, Schottky, Raspberry Pi Zero 2 W
54548-2271, 22 Pin FPC Connector, Raspberry Pi Zero 2 W
Mini HDMI Receptacle Port, Raspberry Pi Zero 2 W
PAM2306AYPKE, Switching Voltage Regulators Dual PWM Step-Down 40uA 1A 1.5MHz, Raspberry Pi Zero 2 W
RT9081A-1BGQZA, Fixed LDO Voltage Regulator, 0.8V-5.5Vin, 140mV drop, 1.25Vout, 0.5Aout, Raspberry Pi Zero 2 W_default
RT8088AWSC, IC Reg Buck Prog 3A Sync 15WLCSP, Raspberry Pi Zero 2 W_default
SMD Inductor, Configurable, Raspberry Pi Zero 2 W_L1
SMD Inductor, Configurable, Raspberry Pi Zero 2 W_L2
SMD Capacitor, Configurable, Raspberry Pi Zero 2 W_C1 x 3
SMD Capacitor, Configurable, Raspberry Pi Zero 2 W_C3 x 7
SMD Capacitor, Configurable, Raspberry Pi Zero 2 W_C2 x 31
SMD Capacitor, Configurable, Raspberry Pi Zero 2 W_C10 x 15
SMD Resistor, Configurable, Raspberry Pi Zero 2 W_R1 x 20
SMD Resistor, Configurable, Raspberry Pi Zero 2 W_R12
Lötende x 2
PinSocket_2x26_P2.54mm_Vertical x 2
Mission Pegasus_PCB

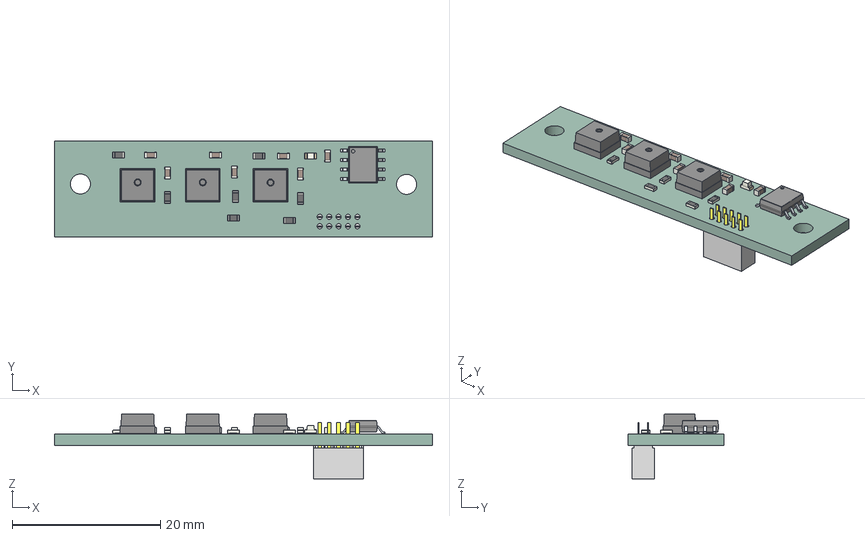
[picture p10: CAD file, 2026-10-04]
mezzanine-board/sensorboard3.step
51.0 x 13.0 x 8.73 mm
C_0603_1608Metric x 7
AS72651-BLGT x 3
R_0603_1608Metric x 7
LED_0603_1608Metric
PinsArrayLR
SFMC-105-01_socket
C-05-01_spins
sensorPCB_PCB

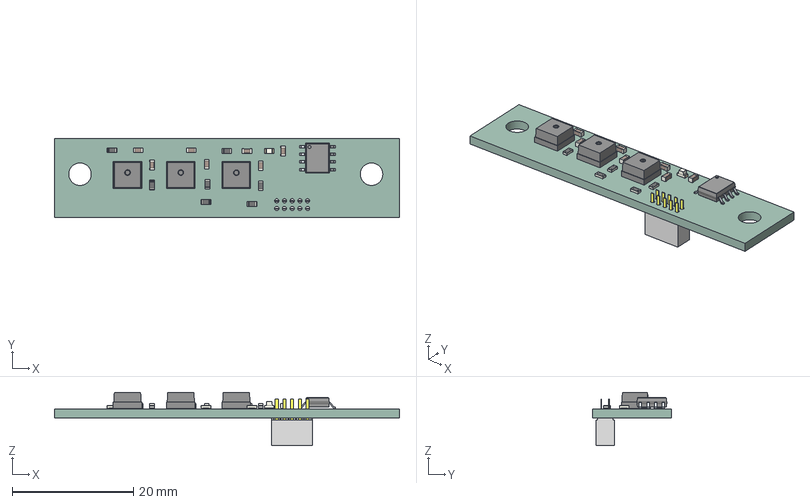
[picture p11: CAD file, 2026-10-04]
Peter's Files/sensor-board/sensorboardCAD/sensorboard5.step
56.8 x 13.0 x 8.73 mm
C_0603_1608Metric x 7
AS72651-BLGT x 3
R_0603_1608Metric x 7
LED_0603_1608Metric
PinsArrayLR
SFMC-105-01_socket
C-05-01_spins
sensorPCB_PCB

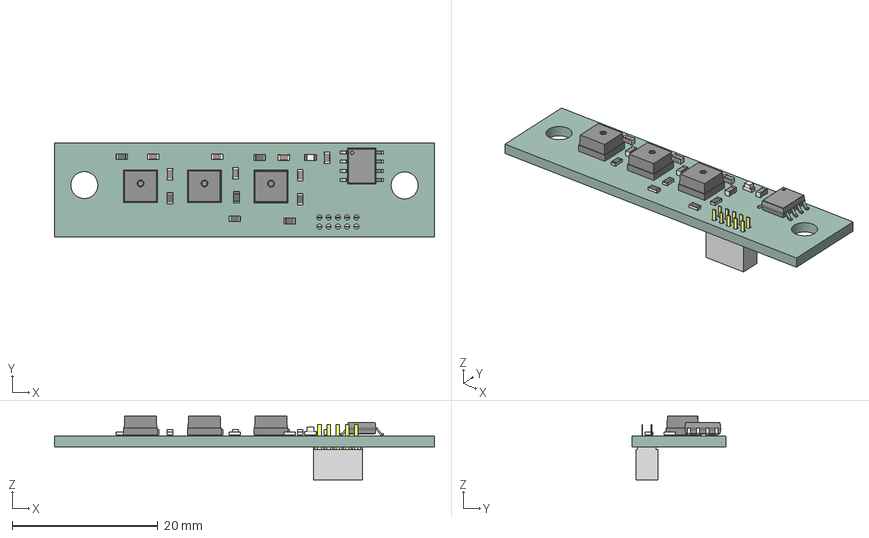
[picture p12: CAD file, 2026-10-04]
mezzanine-board/sensorboard4.step
52.2 x 13.0 x 8.73 mm
C_0603_1608Metric x 7
AS72651-BLGT x 3
R_0603_1608Metric x 7
LED_0603_1608Metric
PinsArrayLR
SFMC-105-01_socket
C-05-01_spins
sensorPCB_PCB

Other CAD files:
main-board/mainboard.step
main-board/mainboard4.step
main-board/mainboard5.step
mezzanine-board/sensorboard2.step
main-board/sensorboard5.step
mezzanine-board/sensorboard.step
CAD/615Bracket.ipt
CAD/OldVersions/PCBAssembly.0006.iam
CAD/OldVersions/PCBAssemblyFEA.0001.iam
CAD/PCBAssembly.iam
CAD/PCBAssemblyFEA.iam
Peter's Files/CAD/615Bracket.ipt
Peter's Files/CAD/OldVersions/PCBAssembly.0006.iam
Peter's Files/CAD/OldVersions/PCBAssemblyFEA.0001.iam
Peter's Files/CAD/PCBAssembly.iam
Peter's Files/CAD/PCBAssemblyFEA.iam
Peter's Files/CAD/PCBboard.ipt
Peter's Files/main-board/mainboardCAD/mainboard6.ipt
Peter's Files/sensor-board/sensorboardCAD/sensorboard5.ipt
main-board/mainboard/10.ipt
main-board/mainboard/54548-2271, 22 Pin FPC Connector, Raspberry Pi Zero 2 W.ipt
main-board/mainboard/7427927161.iam
main-board/mainboard/74279273.ipt
main-board/mainboard/ASSEMBLY.iam
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

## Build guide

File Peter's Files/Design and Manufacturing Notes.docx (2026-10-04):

Design and Manufacturing

Project aim

Create a prototype board for the school to implement into a cubesat. The aim was to create a single board which combines the Sparkfun Triad Spectoscopy Sensor (https://www.sparkfun.com/sparkfun-triad-spectroscopy-sensor-as7265x-qwiic.html#content-documentation) with a Raspberry Pi 0 2w.

This part is currently out of stock, and the sensors are scheduled for obsolescence.

Design considerations

The first step was to recreate the circuit necessary for the chips. An important thing to note is that the Sparkfun circuit is out of date as it uses the old version of the firmware.

Use the latest datasheet which can be found here (https://ams-osram.com/products/sensor-solutions/ambient-light-color-spectral-proximity-sensors/ams-as7265x-smart-spectral-sensor)

The firmware changes around some of the pins.

The main board was aimed to be designed to the librecube standards (https://librecube.gitlab.io/)

This set the physical dimensions of the board and a limit on the height of components attached to it.

Early in the design phase it was decided to split the circuit into two boards.

One main board with a perpendicular smaller board attached with right angled connectors.

This was done due to uncertainty as to where the board would be placed in the cubesat. If the sensors were placed directly onto s typical cubesat board it would be pointing directly at another board (unless it was on the top layer which was not guaranteed.

The sensor board was initially designed to not exceed the height of 8.76 mm. This was achieved after some difficult routing but due to the height of the right-angled connector, it would not have been possible to mount it to the board to the mainboard.

The sensor board was redesigned to have a height of 12mm which was much easier to route and remained between the 16mm spacing between boards (assuming nothing is placed underneath the PCB above it.

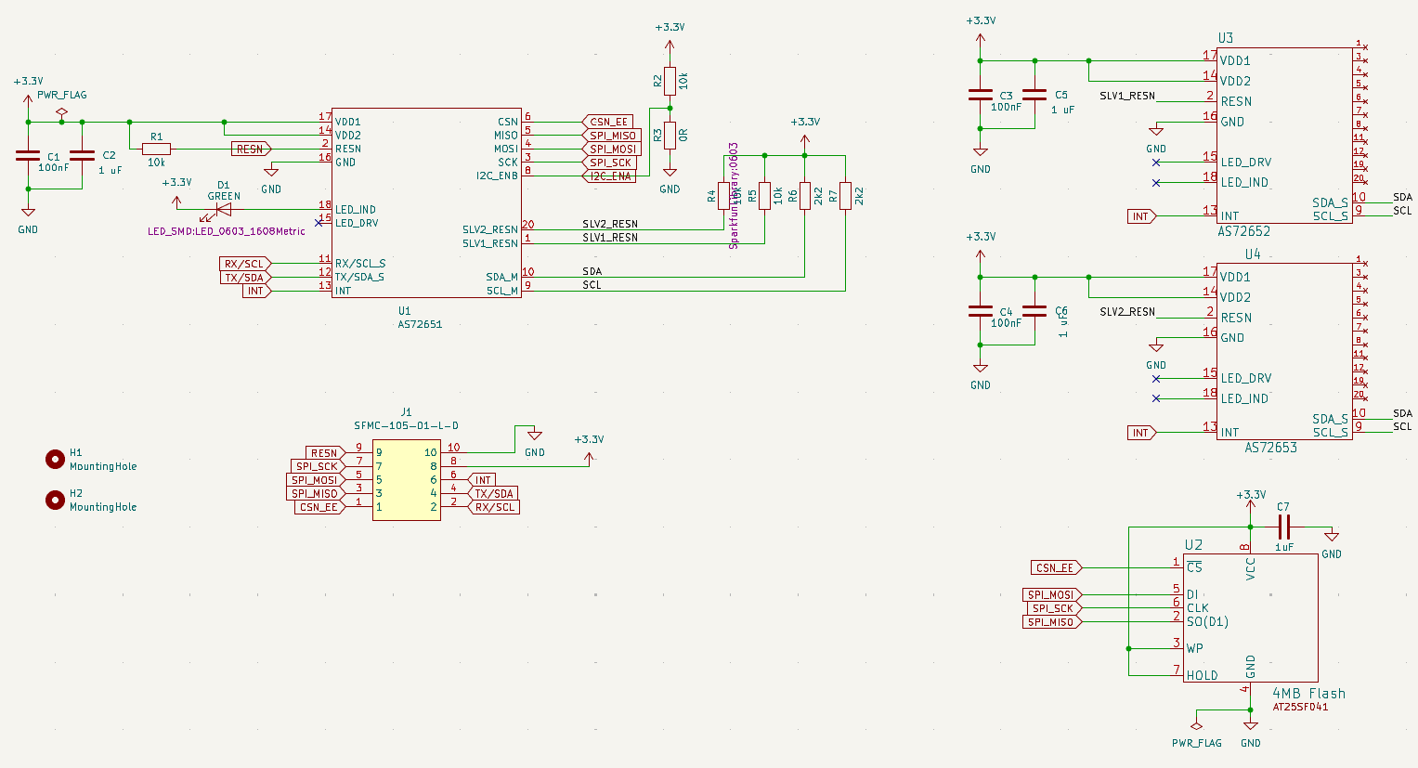
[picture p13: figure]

Schematic

Routing

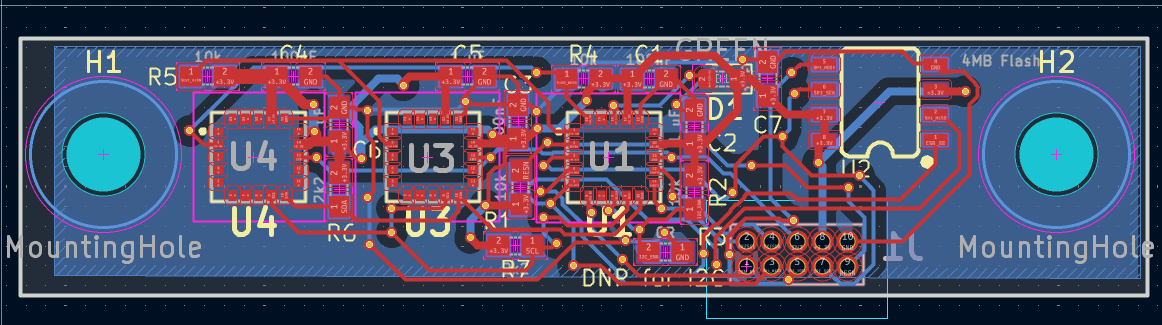
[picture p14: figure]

3D view

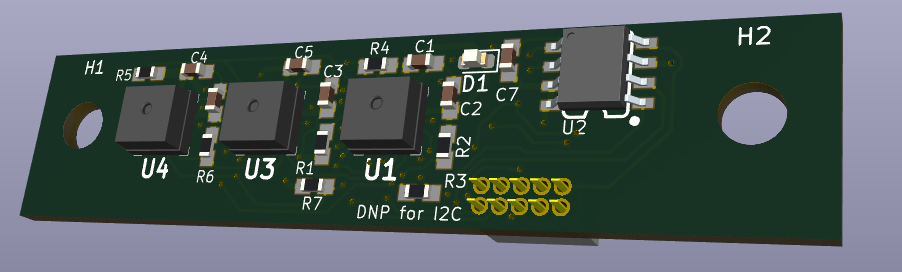
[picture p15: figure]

To provide flexibility, it was decided to make this sensor board to be able to be placed in 3 different locations each pointing to a different side of the cubesat.

The school had initially used UART to communicate with the sensors so it was decided to add the flexibility of switching between UART and I2C by using 0 ohm resistors.

Additionally, the option to test the UART between layers of the cubesat was added by connecting the pi to the stacking connectors.

Final Assembly

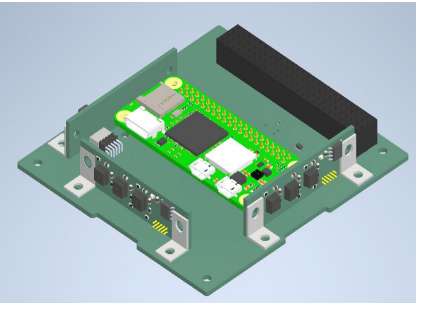
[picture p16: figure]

Includes the 3 possible configurations

Assembly

The PCBs were assembled by hand and heated using a hot plate.

An initial test of the sensor board was done.

This was done by using a power supply.

A positive result was determined by having the PCB draw no more than 15mA and the LED flashing.

The LED flashing is due to the sensors waiting to have their firmware uploaded.

If the firmware had been successfully uploaded, then the light would remain red and not flash.

Issues

There were some issues with uploading the firmware once the chip was already on the board. This could have been due to difficulty in reaching the pins with the programmer or something else. There were also some issues with reading certain chips after they had been flashed and some started flashing after they had been power cycled.

Eventually, some sensor boards would remain red but when they were connected to the main board they would start flashing.

We were uncertain as to why this was the case.

This did not happen with one board which had a short between the SDA and SCL line so could not be used.

It was uncertain as to whether this was due to the board being correct apart from this or it remained solid due to another fault.

There was also an issue with overheating of the SD card holder. This would get very hot to touch after just a few seconds, but the issue was fixed when we changed SD cards.

To test whether the boards worked we used a script to check whether the pi could communicate with the board over I2c.

All tests for this failed.

A successful test would show presence of something at the memory address 49 however all tests showed nothing there.

We could not find out what was the cause of the issues.

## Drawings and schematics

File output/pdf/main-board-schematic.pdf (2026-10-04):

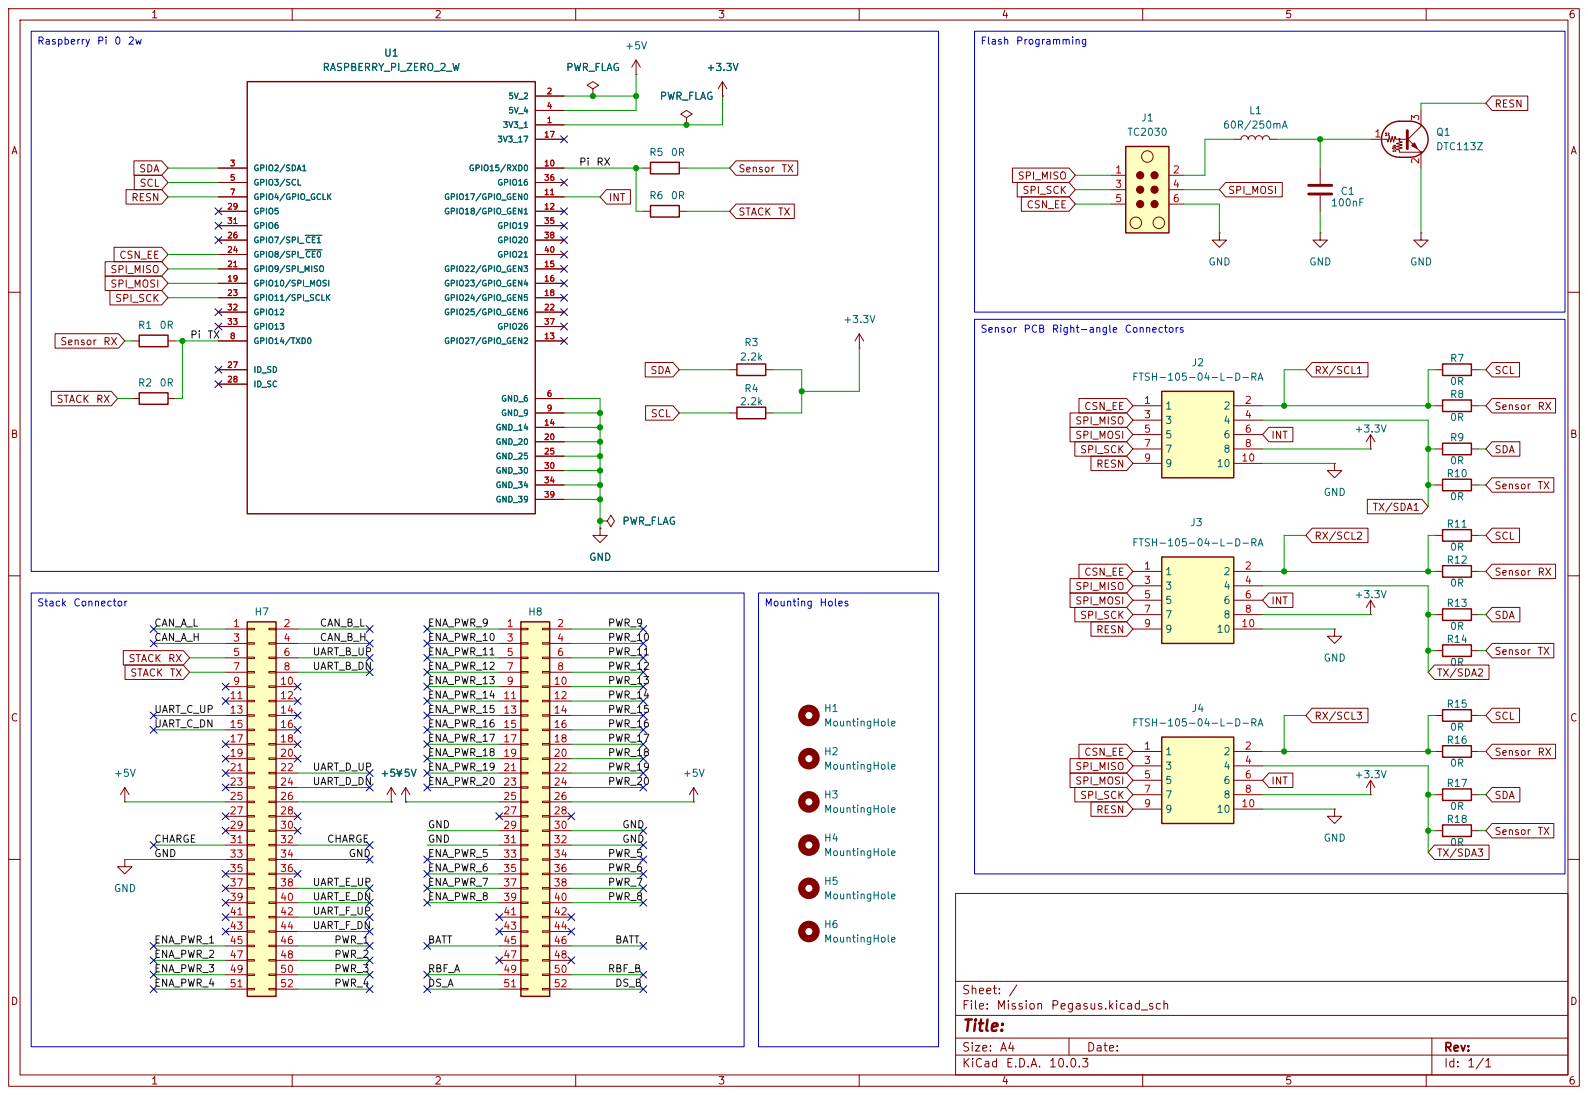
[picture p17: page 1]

STACK RX CSN_EE SDA RESN
SCL SPI_SCK

SDA SCL Sensor TX CSN_EE SPI_SCK
RESN

Size: A4 | Rev:
KiCad E.D.A. 10.0.3 | Id: 1/1

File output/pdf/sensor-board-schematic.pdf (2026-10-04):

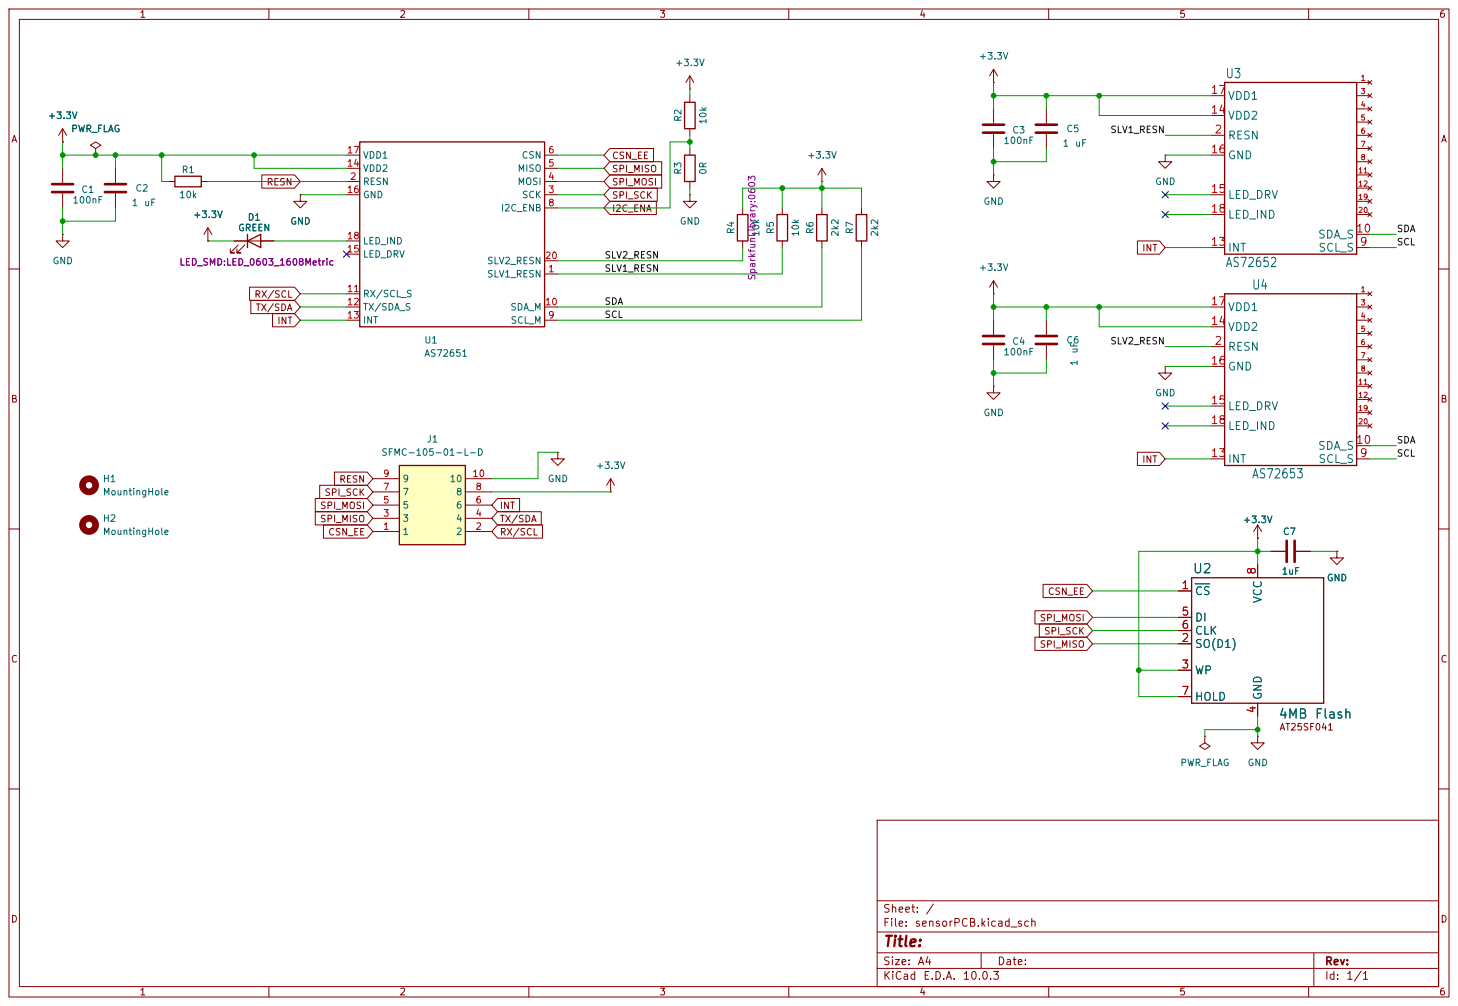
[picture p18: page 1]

Size: A4 | Rev:
KiCad E.D.A. 10.0.3 | Id: 1/1

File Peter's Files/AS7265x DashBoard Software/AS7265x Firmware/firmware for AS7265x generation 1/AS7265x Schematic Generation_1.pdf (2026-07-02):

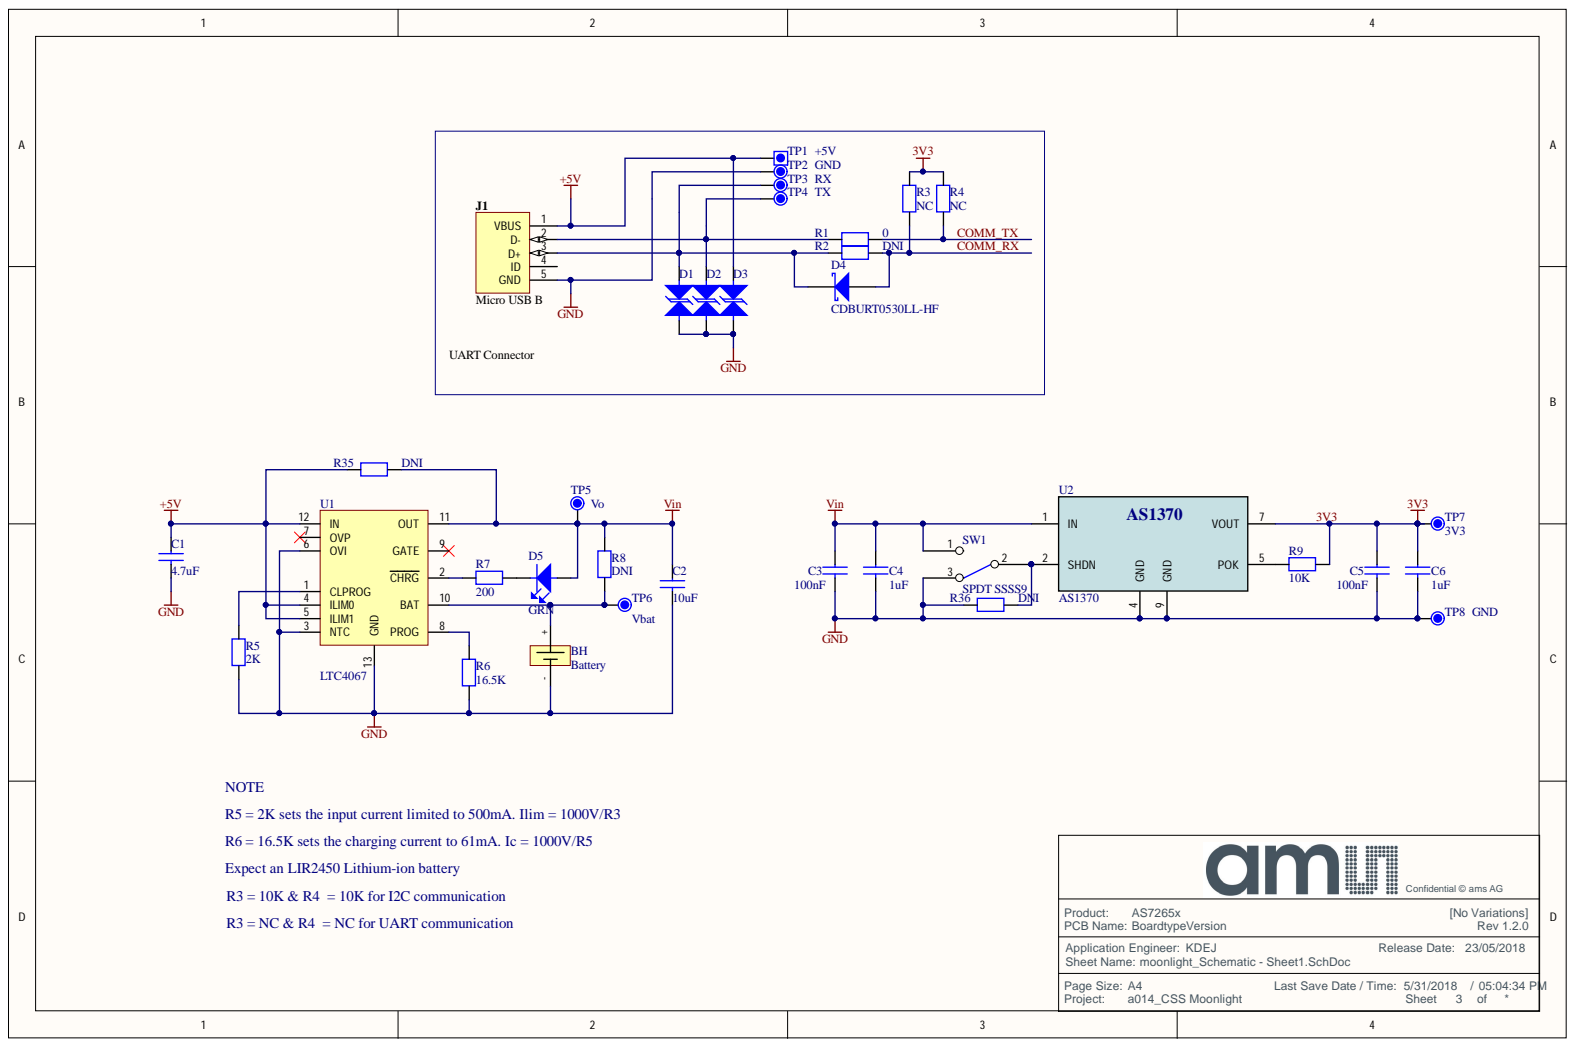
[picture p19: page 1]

OVI 6

CLPROG 1
ILIM0 4
NTC 3 ILIM1 5

R5 = 2K sets the input current limited to 500mA. Ilim = 1000V/R3

R6 = 16.5K sets the charging current to 61mA. Ic = 1000V/R5

Expect an LIR2450 Lithium-ion battery

R3 = NC & R4 = NC for UART communication

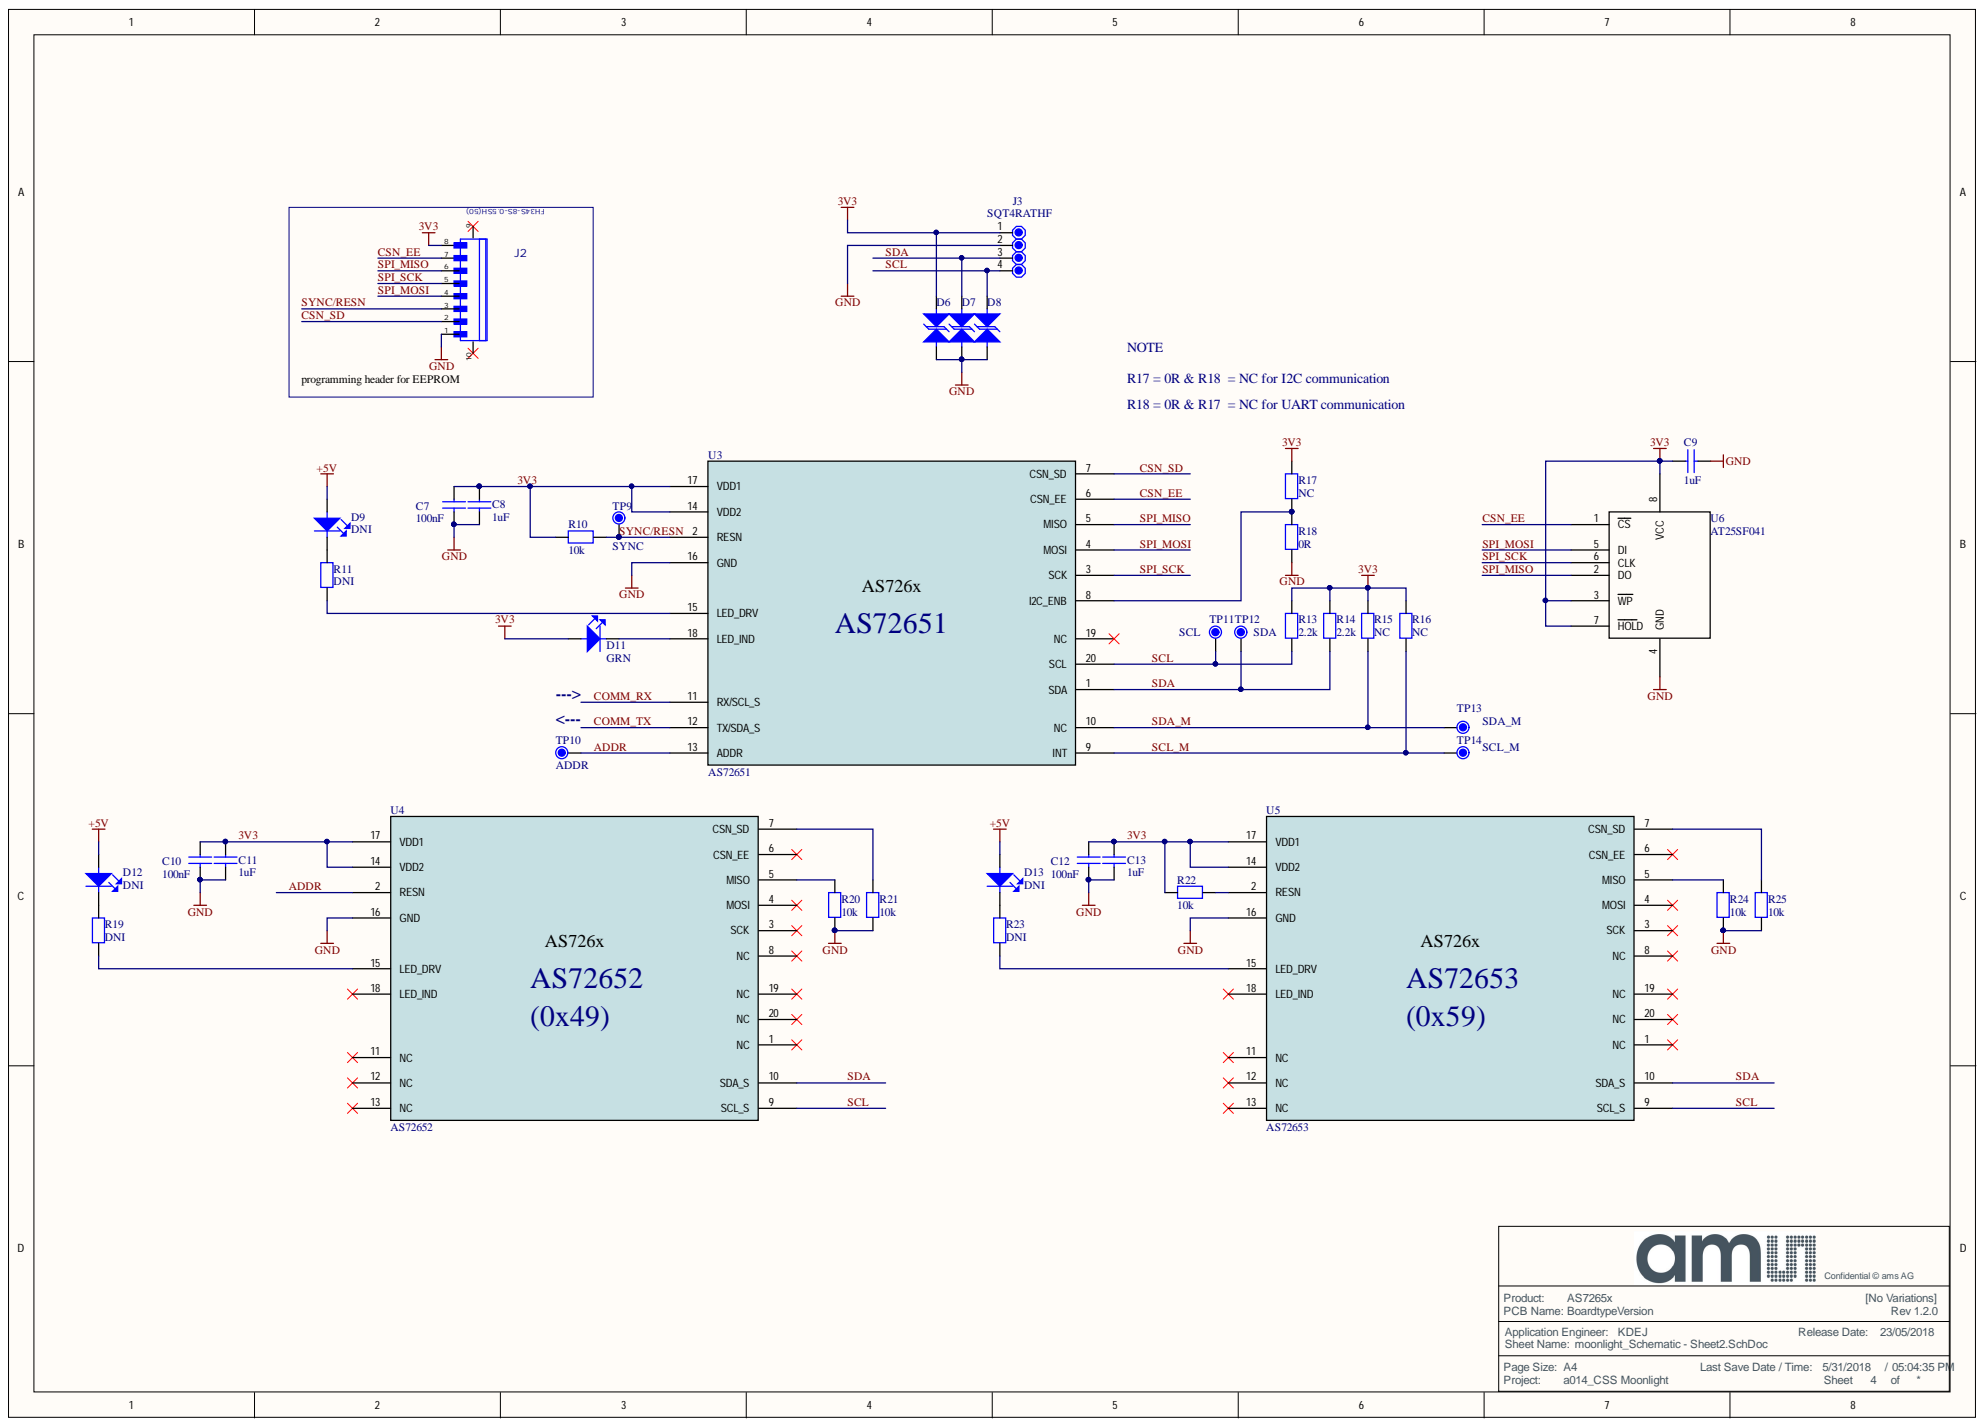
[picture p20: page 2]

programming header for EEPROM

R18 = 0R & R17 = NC for UART communication

SCL

SDA

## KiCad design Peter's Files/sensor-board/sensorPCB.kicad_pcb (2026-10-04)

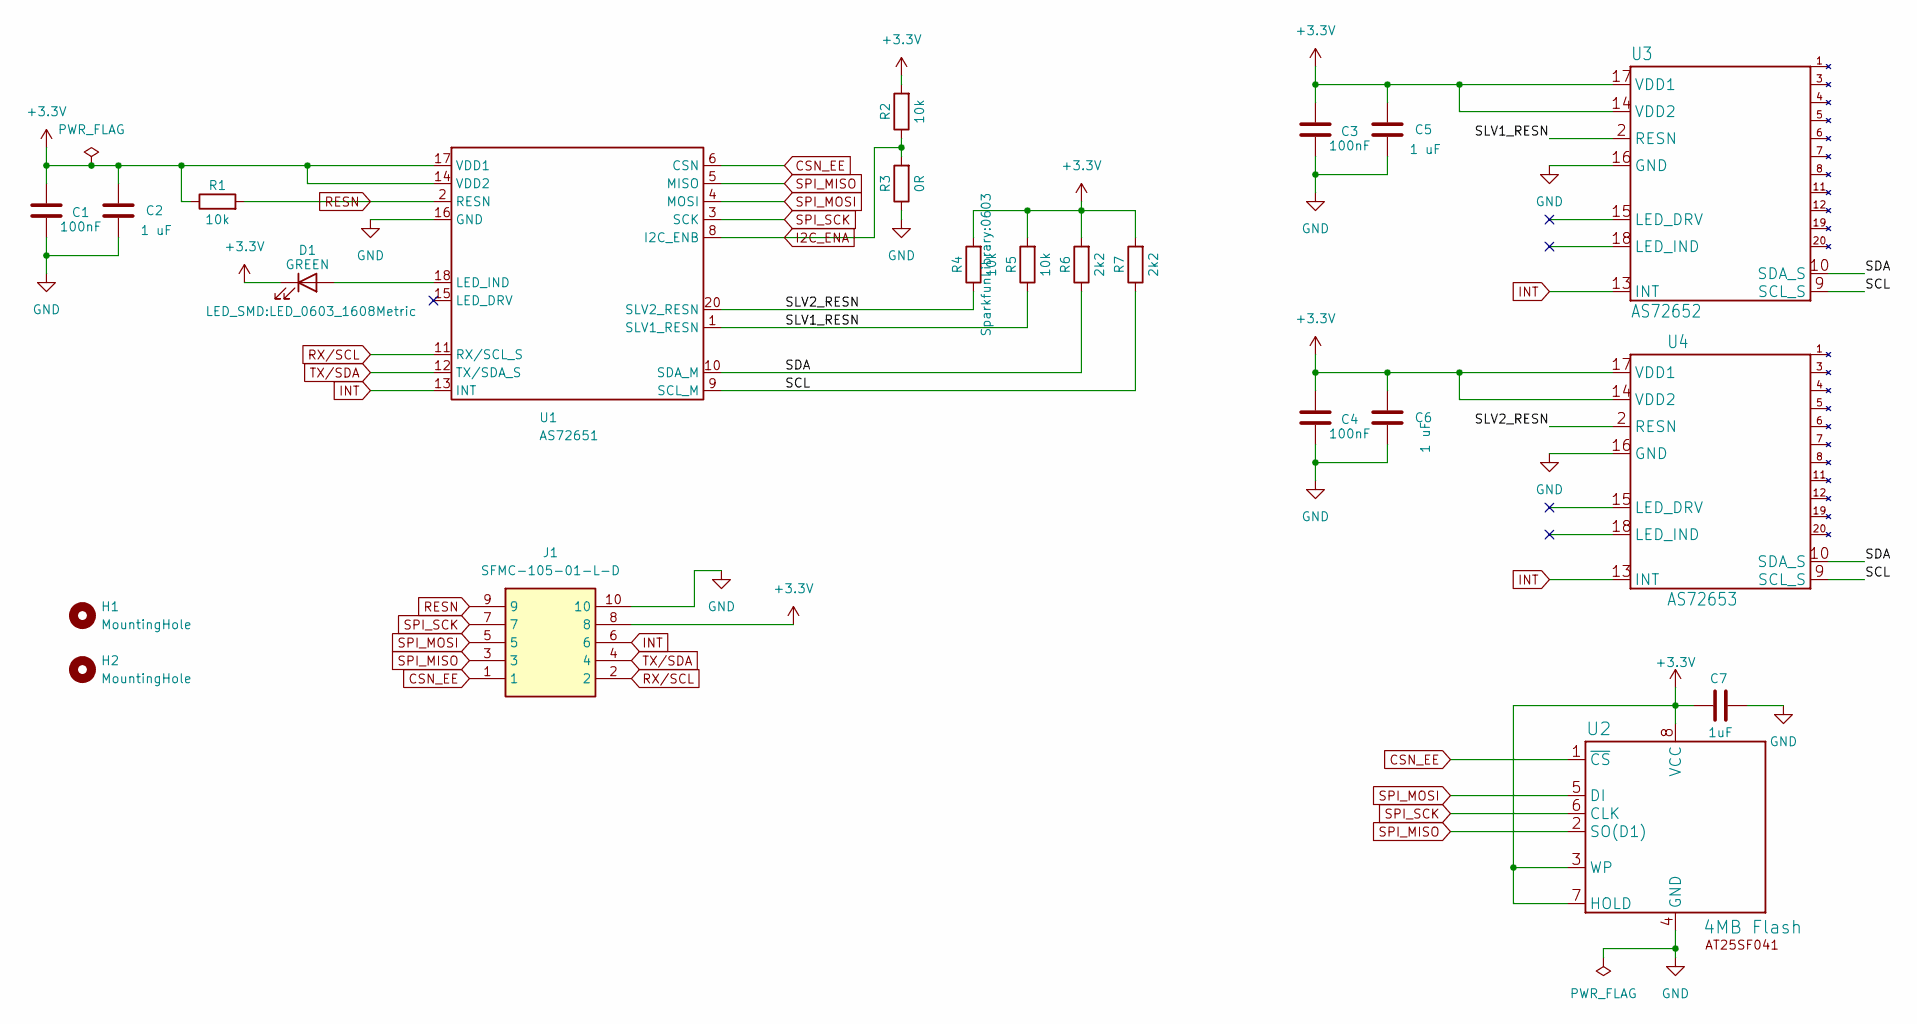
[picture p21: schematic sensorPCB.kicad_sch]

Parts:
C1, C3, C4: 100nF; 0603
C2, C5, C6: 1 uF; 0603
C7: 1uF; 0603
D1: GREEN; LED_0603_1608Metric
H1, H2: MountingHole; MountingHole_3.7mm
J1: SFMC-105-01-L-D; SFMC-105-XX-YY-D; Manufacturer_Part_Number SFMC-105-01-L-D; Mouser Part Number 200-SFMC10501LD
R1, R2, R4, R5: 10k; 0603
R3: 0R; 0603
R6, R7: 2k2; 0603
U1: AS72651; AS72651BLGT
U2: 4MB Flash; 4MbFlash
U3: AS72652; AS72651BLGT
U4: AS72653; AS72651BLGT

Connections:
+3.3V: C1.1, C2.1, C3.1, C4.1, C5.1, C6.1, C7.1, D1.1 (K), J1.8, R1.1, R2.2, R4.2, R5.2, R6.2, R7.2, U1.14 (VDD2), U1.17 (VDD1), U2.3 (WP), U2.7 (HOLD), U2.8 (VCC), U3.14 (VDD2), U3.17 (VDD1), U4.14 (VDD2), U4.17 (VDD1)
/SCL: R7.1, U1.9 (SCL_M), U3.9 (SCL_S), U4.9 (SCL_S)
/SDA: R6.1, U1.10 (SDA_M), U3.10 (SDA_S), U4.10 (SDA_S)
/SLV1_RESN: R5.1, U1.1 (SLV1_RESN), U3.2 (RESN)
/SLV2_RESN: R4.1, U1.20 (SLV2_RESN), U4.2 (RESN)
CSN_EE: J1.1, U1.6 (CSN), U2.1 (~CS)
GND: C1.2, C2.2, C3.2, C4.2, C5.2, C6.2, C7.2, J1.10, R3.1, U1.16 (GND), U2.4 (GND), U3.16 (GND), U4.16 (GND)
I2C_ENA: R2.1, R3.2, U1.8 (I2C_ENB)
INT: J1.6, U1.13 (INT), U3.13 (INT), U4.13 (INT)
unnamed: D1.2 (A), U1.18 (LED_IND)
RESN: J1.9, R1.2, U1.2 (RESN)
RX/SCL: J1.2, U1.11 (RX/SCL_S)
SPI_MISO: J1.3, U1.5 (MISO), U2.2 (SO(D1))
SPI_MOSI: J1.5, U1.4 (MOSI), U2.5 (DI)
SPI_SCK: J1.7, U1.3 (SCK), U2.6 (CLK)
TX/SDA: J1.4, U1.12 (TX/SDA_S)

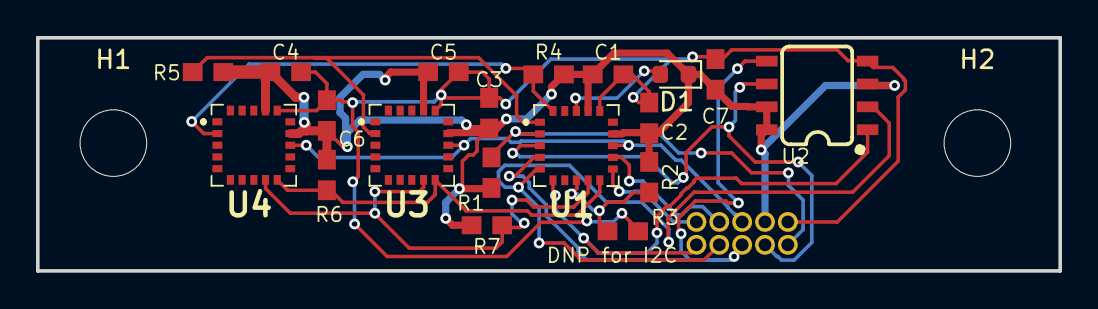
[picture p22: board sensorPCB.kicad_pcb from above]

Board: 2 copper layers, 56.8 x 13.0 mm, 22 parts (1 on the bottom side), 16 nets.

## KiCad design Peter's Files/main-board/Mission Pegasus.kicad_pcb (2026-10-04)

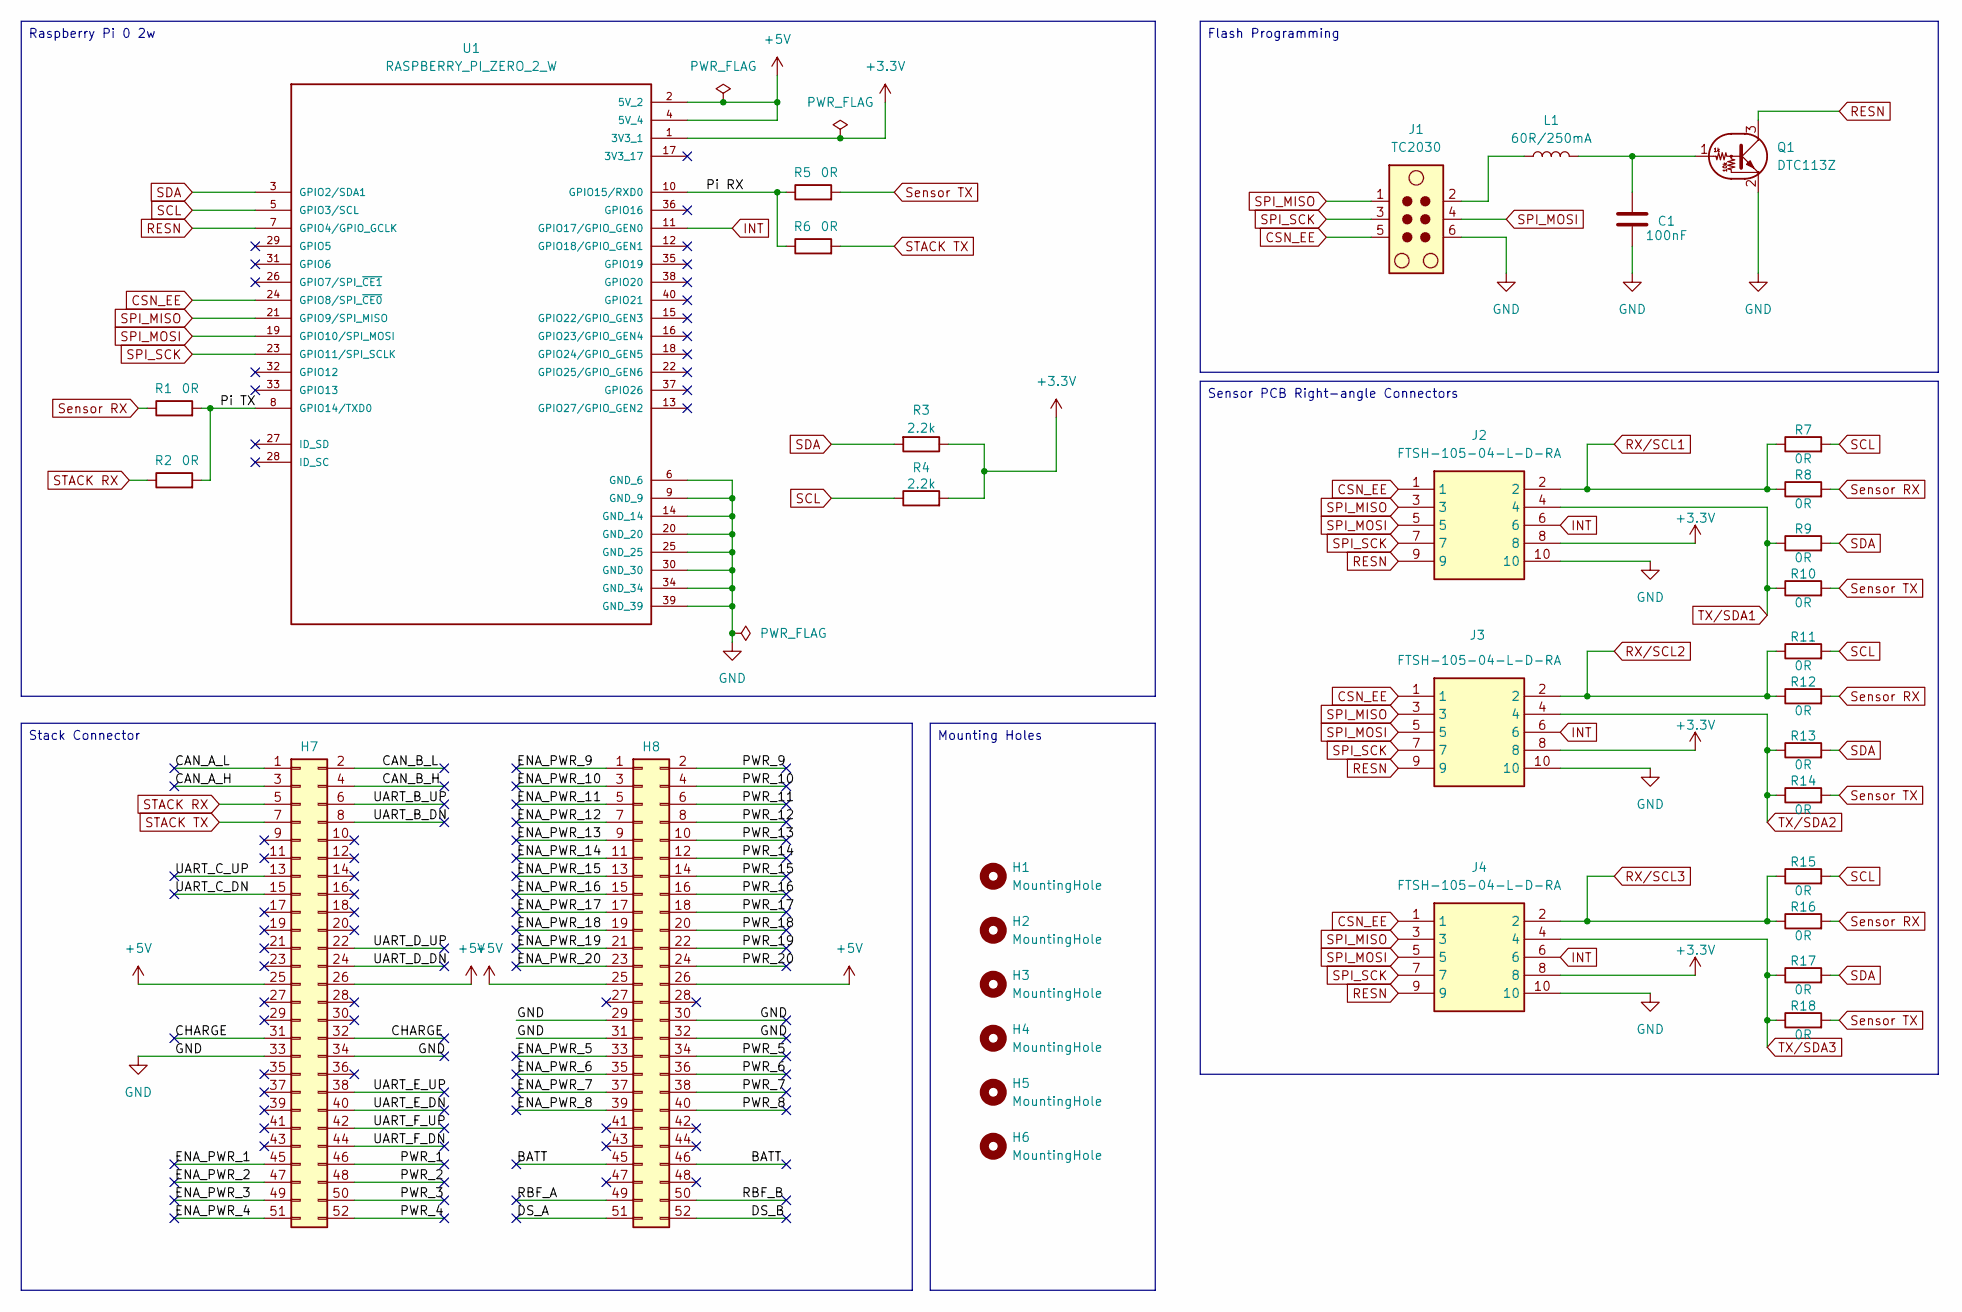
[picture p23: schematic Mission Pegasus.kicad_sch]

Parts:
C1: 100nF; 0603
H1, H2, H3, H4, H5, H6: MountingHole; MountingHole_3.2mm_M3
H7, H8: PC/104 Connector; PinSocket_2x26_P2.54mm_Vertical
J1: TC2030; Tag-Connect_TC2030-IDC-NL_2x03_P1.27mm_Vertical
J2, J3, J4: FTSH-105-04-L-D-RA; FTSH-105-XX-YYY-D-RA; Manufacturer_Part_Number FTSH-105-04-L-D-RA; Mouser Part Number 200-FTSH10504LDRA
L1: 60R/250mA; 0402
Q1: DTC113Z; DTC113ZUA
R1, R2, R5, R6, R7, R8, R9, R10, R11, R12, R13, R14, R15, R16, R17, R18: 0R; R_0603_1608Metric
R3, R4: 2.2k; 0603
U1: RASPBERRY_PI_ZERO_2_W; RASPBERRYPI-ZERO_RPI-ZERO; PARTREV April 2024

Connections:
+3.3V: J2.8, J3.8, J4.8, R3.1, R4.2, U1.1 (3V3_1)
+5V: H7.25, H7.26, H8.25, H8.26, U1.2 (5V_2), U1.4 (5V_4)
/BATT: H8.45, H8.46
/CAN_A_H: H7.3
/CAN_A_L: H7.1
/CAN_B_H: H7.4
/CAN_B_L: H7.2
/CHARGE: H7.31, H7.32
/DS_A: H8.51
/DS_B: H8.52
/ENA_PWR_1: H7.45
/ENA_PWR_2: H7.47
/ENA_PWR_3: H7.49
/ENA_PWR_4: H7.51
/ENA_PWR_5: H8.33
/ENA_PWR_6: H8.35
/ENA_PWR_7: H8.37
/ENA_PWR_8: H8.39
/ENA_PWR_9: H8.1
/ENA_PWR_10: H8.3
/ENA_PWR_11: H8.5
/ENA_PWR_12: H8.7
/ENA_PWR_13: H8.9
/ENA_PWR_14: H8.11
/ENA_PWR_15: H8.13
/ENA_PWR_16: H8.15
/ENA_PWR_17: H8.17
/ENA_PWR_18: H8.19
/ENA_PWR_19: H8.21
/ENA_PWR_20: H8.23
/PWR_1: H7.46
/PWR_2: H7.48
/PWR_3: H7.50
/PWR_4: H7.52
/PWR_5: H8.34
/PWR_6: H8.36
/PWR_7: H8.38
/PWR_8: H8.40
/PWR_9: H8.2
/PWR_10: H8.4
/PWR_11: H8.6
/PWR_12: H8.8
/PWR_13: H8.10
/PWR_14: H8.12
/PWR_15: H8.14
/PWR_16: H8.16
/PWR_17: H8.18
/PWR_18: H8.20
/PWR_19: H8.22
/PWR_20: H8.24
/Pi RX: R5.1, R6.1, U1.10 (GPIO15/RXD0)
/Pi TX: R1.2, R2.2, U1.8 (GPIO14/TXD0)
/RBF_A: H8.49
/RBF_B: H8.50
/UART_B_DN: H7.8
/UART_B_UP: H7.6
/UART_C_DN: H7.15
/UART_C_UP: H7.13
/UART_D_DN: H7.24
/UART_D_UP: H7.22
/UART_E_DN: H7.40
/UART_E_UP: H7.38
/UART_F_DN: H7.44
/UART_F_UP: H7.42
CSN_EE: J1.5, J2.1, J3.1, J4.1, U1.24 (GPIO8/SPI_~CE0)
GND: C1.2, H7.33, H7.34, H8.29, H8.30, H8.31, H8.32, J1.6, J2.10, J3.10, J4.10, Q1.2 (E), U1.6 (GND_6), U1.9 (GND_9), U1.14 (GND_14), U1.20 (GND_20), U1.25 (GND_25), U1.30 (GND_30), U1.34 (GND_34), U1.39 (GND_39)
INT: J2.6, J3.6, J4.6, U1.11 (GPIO17/GPIO_GEN0)
unnamed: J1.2, L1.1
unnamed: C1.1, L1.2, Q1.1 (B)
RESN: J2.9, J3.9, J4.9, Q1.3 (C), U1.7 (GPIO4/GPIO_GCLK)
RX/SCL1: J2.2, R7.1, R8.1
RX/SCL2: J3.2, R11.1, R12.1
RX/SCL3: J4.2, R15.1, R16.1
SCL: R4.1, R7.2, R11.2, R15.2, U1.5 (GPIO3/SCL)
SDA: R3.2, R9.2, R13.2, R17.2, U1.3 (GPIO2/SDA1)
SPI_MISO: J1.1, J2.3, J3.3, J4.3, U1.21 (GPIO9/SPI_MISO)
SPI_MOSI: J1.4, J2.5, J3.5, J4.5, U1.19 (GPIO10/SPI_MOSI)
SPI_SCK: J1.3, J2.7, J3.7, J4.7, U1.23 (GPIO11/SPI_SCLK)
STACK RX: H7.5, R2.1
STACK TX: H7.7, R6.2
Sensor RX: R1.1, R8.2, R12.2, R16.2
Sensor TX: R5.2, R10.2, R14.2, R18.2
TX/SDA1: J2.4, R9.1, R10.1
TX/SDA2: J3.4, R13.1, R14.1
TX/SDA3: J4.4, R17.1, R18.1

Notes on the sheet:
Flash Programming
Raspberry Pi 0 2w
Mounting Holes
Stack Connector
Sensor PCB Right-angle Connectors

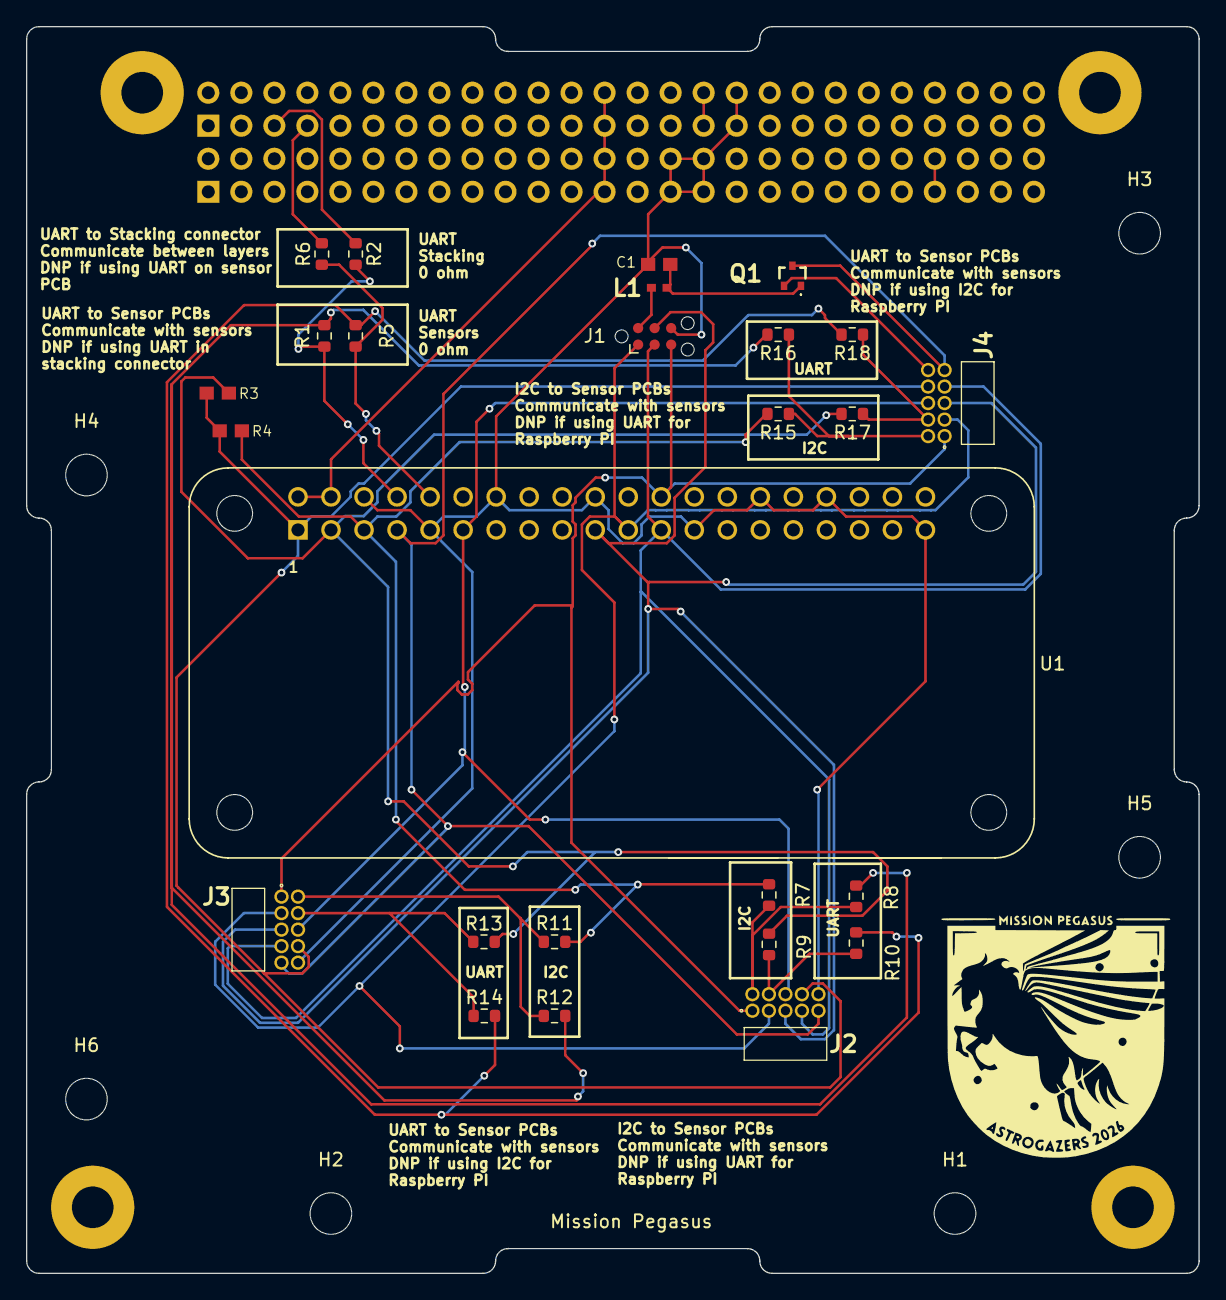
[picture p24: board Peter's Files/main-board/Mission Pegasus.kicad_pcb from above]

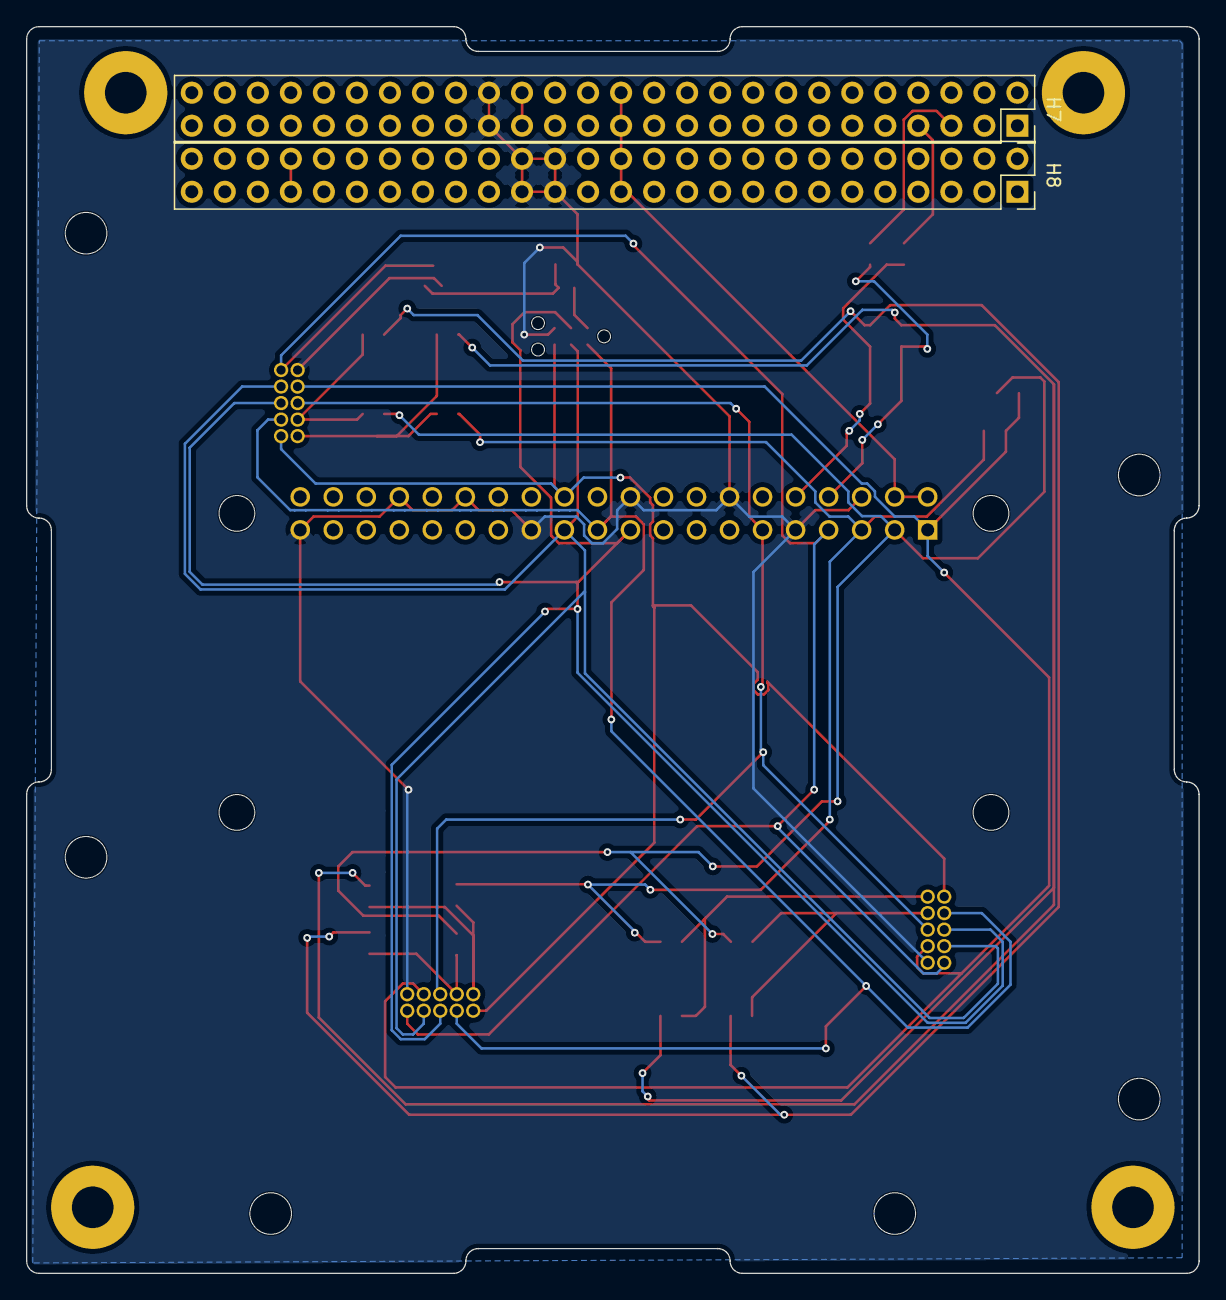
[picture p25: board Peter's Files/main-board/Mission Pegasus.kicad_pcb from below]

Board: 2 copper layers, 90.2 x 95.9 mm, 38 parts (2 on the bottom side), 27 nets.

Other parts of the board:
M1, M2, M3, M4: MountingHole; MountingHole_3.2mm_M3_Pad

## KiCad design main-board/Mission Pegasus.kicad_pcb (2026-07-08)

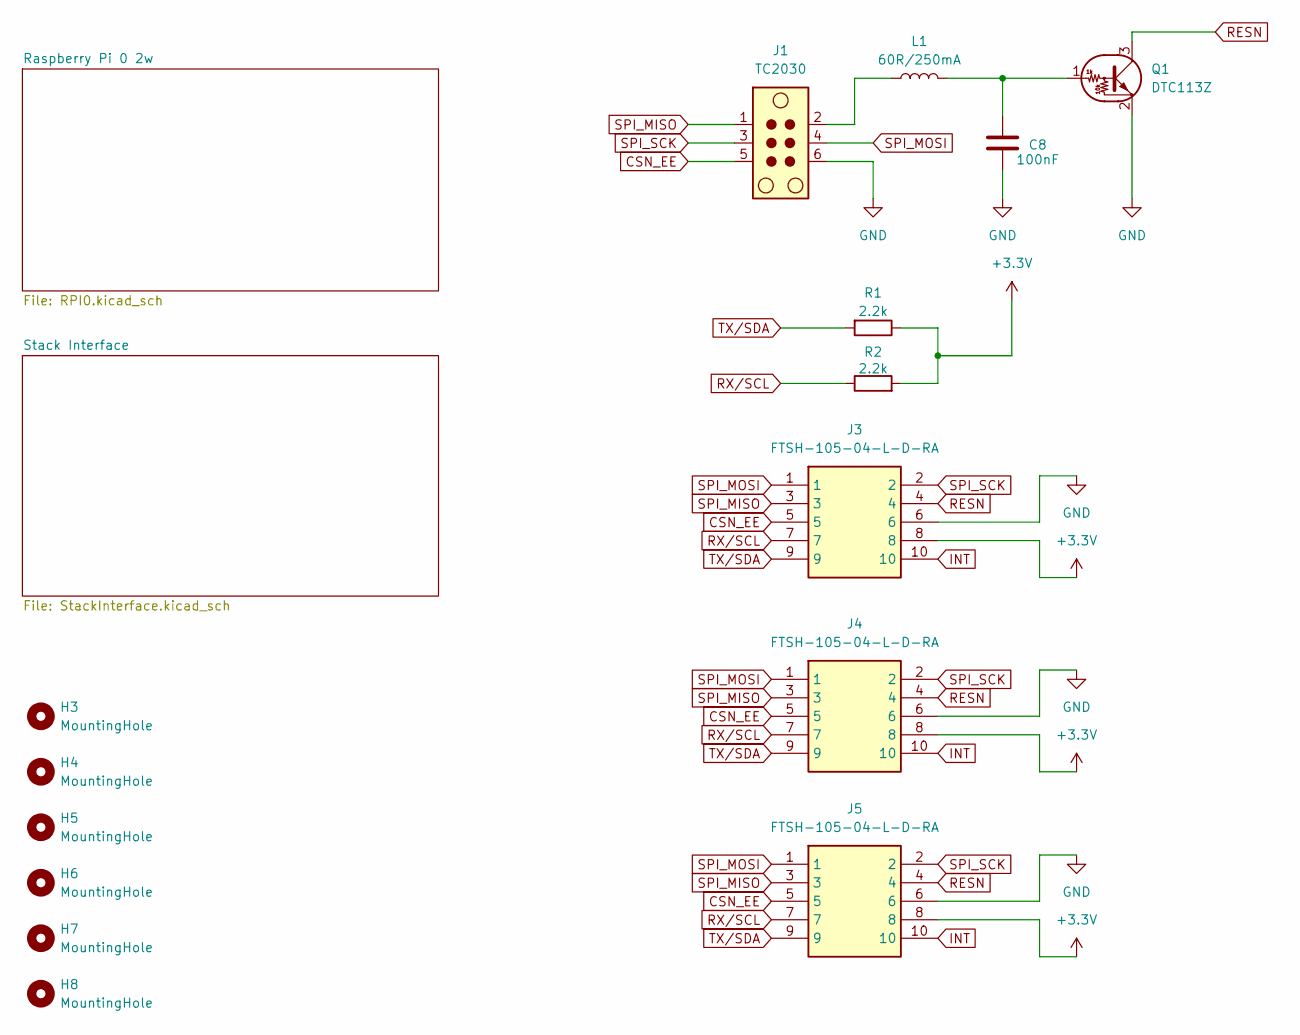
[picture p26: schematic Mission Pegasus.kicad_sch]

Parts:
C8: 100nF; 0603
H3, H4, H5, H6, H7, H8: MountingHole; Mounting_Wuerth_WA-SMSI-M2.5_H0.5mm_9774005151
J1: TC2030; Tag-Connect_TC2030-IDC-NL_2x03_P1.27mm_Vertical
J3, J4, J5: FTSH-105-04-L-D-RA; FTSH-105-XX-YYY-D-RA; Manufacturer_Part_Number FTSH-105-04-L-D-RA; Mouser Part Number 200-FTSH10504LDRA
L1: 60R/250mA; 0402
Q1: DTC113Z; DTC113ZUA
R1, R2: 2.2k; 0603

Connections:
+3.3V: J3.8, J4.8, J5.8, R1.1, R2.2; also elsewhere on the board
CSN_EE: J1.5, J3.5, J4.5, J5.5; also elsewhere on the board
GND: C8.2, J1.6, J3.6, J4.6, J5.6, Q1.2 (E); also elsewhere on the board
INT: J3.10, J4.10, J5.10; also elsewhere on the board
unnamed: J1.2, L1.1
unnamed: C8.1, L1.2, Q1.1 (B)
RESN: J3.4, J4.4, J5.4, Q1.3 (C); also elsewhere on the board
RX/SCL: J3.7, J4.7, J5.7, R2.1; also elsewhere on the board
SPI_MISO: J1.1, J3.3, J4.3, J5.3; also elsewhere on the board
SPI_MOSI: J1.4, J3.1, J4.1, J5.1; also elsewhere on the board
SPI_SCK: J1.3, J3.2, J4.2, J5.2; also elsewhere on the board
TX/SDA: J3.9, J4.9, J5.9, R1.2; also elsewhere on the board

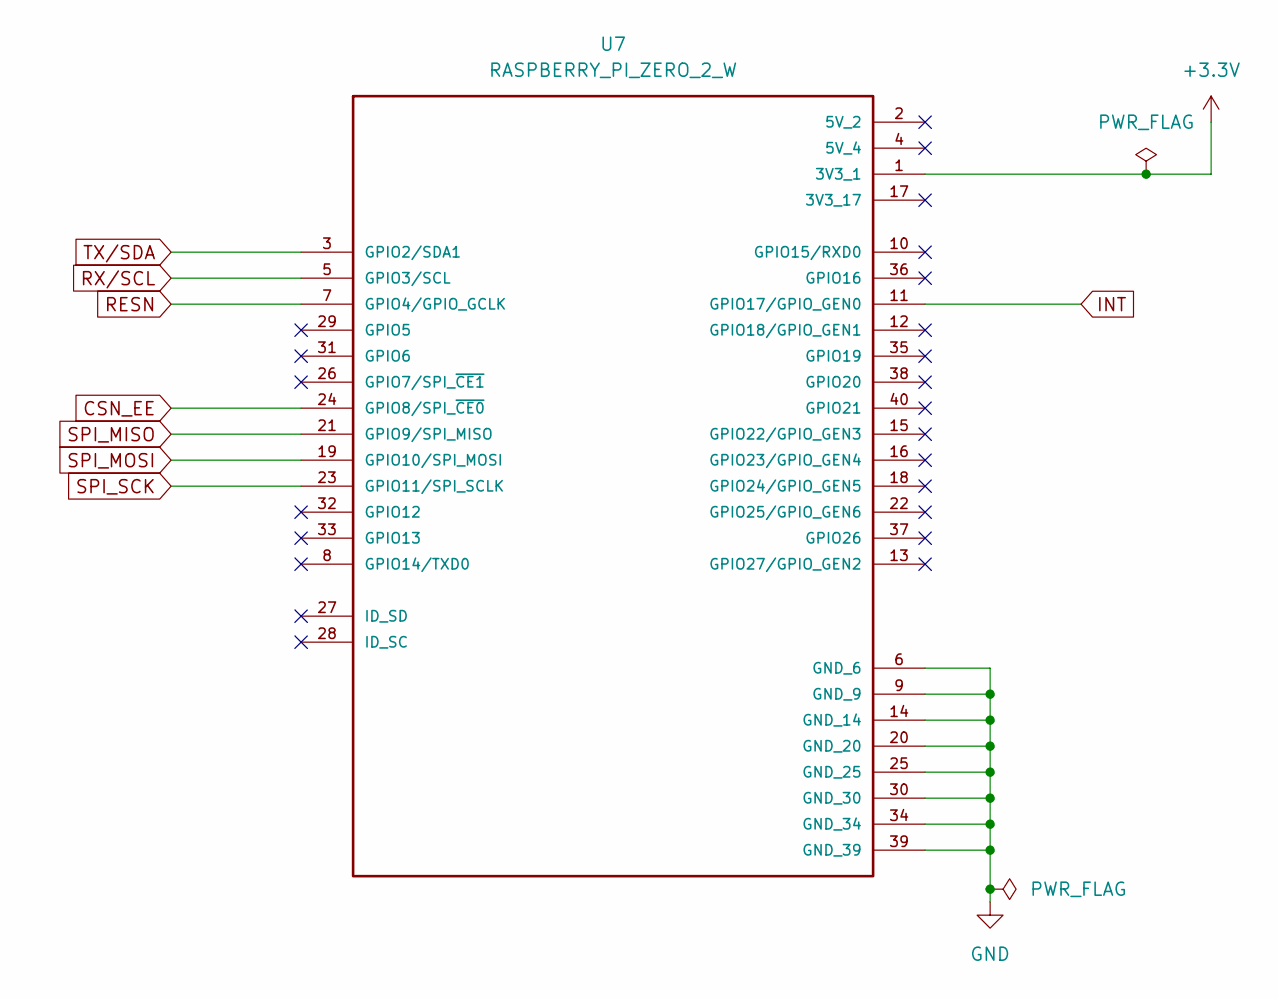
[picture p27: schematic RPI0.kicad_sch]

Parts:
U7: RASPBERRY_PI_ZERO_2_W; RASPBERRYPI-ZERO_RPI-ZERO; PARTREV April 2024

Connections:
+3.3V: U7.1 (3V3_1); also elsewhere on the board
CSN_EE: U7.24 (GPIO8/SPI_~CE0); also elsewhere on the board
GND: U7.6 (GND_6), U7.9 (GND_9), U7.14 (GND_14), U7.20 (GND_20), U7.25 (GND_25), U7.30 (GND_30), U7.34 (GND_34), U7.39 (GND_39); also elsewhere on the board
INT: U7.11 (GPIO17/GPIO_GEN0); also elsewhere on the board
RESN: U7.7 (GPIO4/GPIO_GCLK); also elsewhere on the board
RX/SCL: U7.5 (GPIO3/SCL); also elsewhere on the board
SPI_MISO: U7.21 (GPIO9/SPI_MISO); also elsewhere on the board
SPI_MOSI: U7.19 (GPIO10/SPI_MOSI); also elsewhere on the board
SPI_SCK: U7.23 (GPIO11/SPI_SCLK); also elsewhere on the board
TX/SDA: U7.3 (GPIO2/SDA1); also elsewhere on the board

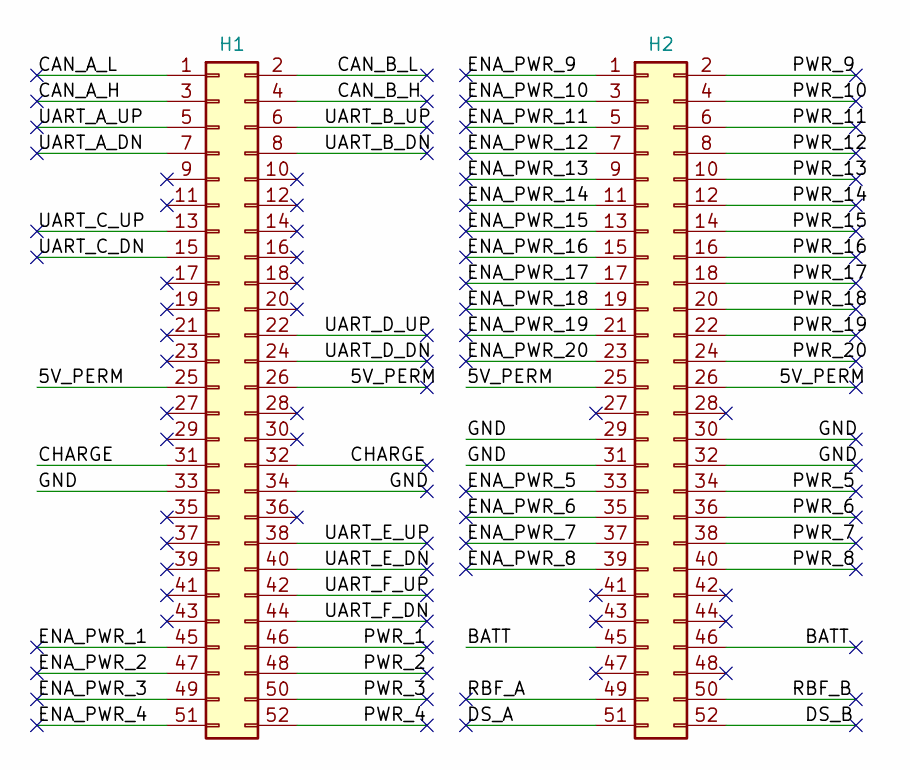
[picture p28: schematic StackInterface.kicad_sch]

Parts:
H1, H2: PC/104 Connector; PinSocket_2x26_P2.54mm_Vertical

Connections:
/Stack Interface/5V_PERM: H1.25, H1.26, H2.25, H2.26
/Stack Interface/BATT: H2.45, H2.46
/Stack Interface/CAN_A_H: H1.3
/Stack Interface/CAN_A_L: H1.1
/Stack Interface/CAN_B_H: H1.4
/Stack Interface/CAN_B_L: H1.2
/Stack Interface/CHARGE: H1.31, H1.32
/Stack Interface/DS_A: H2.51
/Stack Interface/DS_B: H2.52
/Stack Interface/ENA_PWR_1: H1.45
/Stack Interface/ENA_PWR_2: H1.47
/Stack Interface/ENA_PWR_3: H1.49
/Stack Interface/ENA_PWR_4: H1.51
/Stack Interface/ENA_PWR_5: H2.33
/Stack Interface/ENA_PWR_6: H2.35
/Stack Interface/ENA_PWR_7: H2.37
/Stack Interface/ENA_PWR_8: H2.39
/Stack Interface/ENA_PWR_9: H2.1
/Stack Interface/ENA_PWR_10: H2.3
/Stack Interface/ENA_PWR_11: H2.5
/Stack Interface/ENA_PWR_12: H2.7
/Stack Interface/ENA_PWR_13: H2.9
/Stack Interface/ENA_PWR_14: H2.11
/Stack Interface/ENA_PWR_15: H2.13
/Stack Interface/ENA_PWR_16: H2.15
/Stack Interface/ENA_PWR_17: H2.17
/Stack Interface/ENA_PWR_18: H2.19
/Stack Interface/ENA_PWR_19: H2.21
/Stack Interface/ENA_PWR_20: H2.23
/Stack Interface/GND: H1.33, H1.34, H2.29, H2.30, H2.31, H2.32
/Stack Interface/PWR_1: H1.46
/Stack Interface/PWR_2: H1.48
/Stack Interface/PWR_3: H1.50
/Stack Interface/PWR_4: H1.52
/Stack Interface/PWR_5: H2.34
/Stack Interface/PWR_6: H2.36
/Stack Interface/PWR_7: H2.38
/Stack Interface/PWR_8: H2.40
/Stack Interface/PWR_9: H2.2
/Stack Interface/PWR_10: H2.4
/Stack Interface/PWR_11: H2.6
/Stack Interface/PWR_12: H2.8
/Stack Interface/PWR_13: H2.10
/Stack Interface/PWR_14: H2.12
/Stack Interface/PWR_15: H2.14
/Stack Interface/PWR_16: H2.16
/Stack Interface/PWR_17: H2.18
/Stack Interface/PWR_18: H2.20
/Stack Interface/PWR_19: H2.22
/Stack Interface/PWR_20: H2.24
/Stack Interface/RBF_A: H2.49
/Stack Interface/RBF_B: H2.50
/Stack Interface/UART_A_DN: H1.7
/Stack Interface/UART_A_UP: H1.5
/Stack Interface/UART_B_DN: H1.8
/Stack Interface/UART_B_UP: H1.6
/Stack Interface/UART_C_DN: H1.15
/Stack Interface/UART_C_UP: H1.13
/Stack Interface/UART_D_DN: H1.24
/Stack Interface/UART_D_UP: H1.22
/Stack Interface/UART_E_DN: H1.40
/Stack Interface/UART_E_UP: H1.38
/Stack Interface/UART_F_DN: H1.44
/Stack Interface/UART_F_UP: H1.42

Board: 2 copper layers, 22 parts (2 on the bottom side), 16 nets, no tracks yet.

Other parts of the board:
M1, M2, M3, M4: MountingHole; MountingHole_3.2mm_M3_Pad

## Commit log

2026-07-02 Initial commit: Mission Pegasus PCB project
    Add KiCad schematics/PCB, component libraries, and reference docs.
    [.kicad_sch, AS7265_CommandSet 12V1_0.xlsx, Mission Pegasus.csv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]
2026-07-02 Clean up library references and remove unused files
    - Fix broken/external library paths: copy RASPBERRY_PI_ZERO_2_W symbol
    into the project and register SamacSys_Parts and SparkfunLibrary
    footprint libraries in fp-lib-table (previously used but unregistered)
    - Fix 3D model paths that pointed to a stale, now-deleted OneDrive location
    - Remove unused RASPBERRYPI-ZERO symbol library entry
    - Un-ignore Downloaded Parts/ - it's required (SamacSys footprints/3D models)
    - Delete empty stub schematics (RaspberyyPi0.kicad_sch, SpectralSensor.kicad_sch)
    - Remove redundant SamacSys multi-EDA export bundle (only needed the one
    3D model, now relocated into SamacSys_Parts.3dshapes)
    - Trim Sparkfun/ v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
    [.kicad_sch, Mission Pegasus.kicad_pcb, Qwiic_Spectral_Sensor-AS7265x.brd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]
2026-07-02 Add no-connect flags to clear ERC warnings
    Mark intentionally-unconnected pins on the stack interface and top-level
    sheets so ERC no longer flags them.
    [Mission Pegasus.kicad_sch, StackInterface.kicad_sch]
2026-07-02 Restructure project into clear folders
    Consolidate all custom parts libraries under libraries/ (footprints/,
    symbols/, 3dmodels/) and update fp-lib-table, sym-lib-table, and every
    3D-model path in the PCB and footprint files to match. Also fix two
    broken absolute 3D-model paths in the SamacSys footprints that still
    pointed at a deleted "New folder" location.
    Move datasheets and project docs (BOM, component notes, order form,
    block diagram) into docs/, and third-party tooling (AMS dashboard
    software, firmware, FTDI driver) into vendor/.
    Rename Library.pretty -> RPIZERO.pretty so the folder matches its
    library nickname. Add README.md documenting the layout. Delete on-disk
    clutter (VS Code .h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
    [Mission Pegasus.csv, Mission Pegasus.kicad_pcb, Order Request form.xlsx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]
2026-07-02 Restructure into main-board/ + mezzanine-board/ for the 90-degree design
    Move the existing Mission Pegasus design into main-board/ as a
    self-contained KiCad project (all paths are ${KIPRJMOD}-relative and the
    libraries/ folder moved with it, so no path edits were needed).
    Scaffold mezzanine-board/ for the new board that mates perpendicular to
    the main board via the 2x26 stack connector: empty libraries/ subfolders
    (footprints/symbols/3dmodels) plus a README with setup and 90-degree
    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
    [Mission Pegasus.csv, Mission Pegasus.kicad_pcb, Mission Pegasus.kicad_sch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]
2026-07-03 Add AS72651-BLGT and 90152-2140 to mezzanine libraries
    Import both Library Loader (SamacSys) parts into the mezzanine board:
    AS72651-BLGT spectral sensor and the 90152-2140 C-Grid III right-angle
    receptacle. Footprints, merged symbols, and 3D models sorted into
    libraries/{footprints,symbols,3dmodels}/SamacSys_Parts.* and registered
    in new project-local fp-lib-table / sym-lib-table.
    Fix the Library Loader quirks: rewrite bare 3D-model filenames to
    ${KIPRJMOD}-relative paths, and qualify each symbol's Footprint property
    with the SamacSys_Parts library nickname.
    [sensorPCB.kicad_pcb, sensorPCB.kicad_sch]
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2026-07-03 Add Molex 90122-0140 right-angle header to main board libraries
    Import the Library Loader (SamacSys) part into the main board: footprint
    into the registered SamacSys_Parts.pretty, 3D model into
    SamacSys_Parts.3dshapes, and symbol appended to SamacSys_Parts.kicad_sym
    (3D path rewritten to ${KIPRJMOD}-relative, Footprint property qualified
    with the library nickname).
    Register SamacSys_Parts as a symbol library in the main board's
    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
    [sensorPCB.kicad_pcb, sensorPCB.kicad_sch]
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2026-07-03 Add TE 215307-7 connector to mezzanine libraries
    Import the Library Loader part (14-pin TE Connectivity connector) into
    the mezzanine's already-registered SamacSys_Parts library: footprint, 3D
    model, and symbol appended. 3D path rewritten to ${KIPRJMOD}-relative and
    the symbol's Footprint property qualified with the library nickname.
    [sensorPCB.kicad_pcb, sensorPCB.kicad_sch]
2026-07-03 Add Molex 90122-0770 right-angle header to main board libraries
    Import the Library Loader part (2x10 right-angle header, 20-pin) into the
    main board's SamacSys_Parts library: footprint, 3D model, and symbol
    appended. 3D path rewritten to ${KIPRJMOD}-relative and the symbol's
    Footprint property qualified with the library nickname.
    [sensorPCB.kicad_pcb]
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2026-07-03 Add Samtec FTSH-110-01-F-D-RA header to mezzanine libraries
    Import the Library Loader part (2x10 right-angle 1.27mm fine-pitch header)
    into the mezzanine's SamacSys_Parts library: footprint, 3D model, and
    symbol appended. 3D path rewritten to ${KIPRJMOD}-relative and the
    symbol's Footprint property qualified with the library nickname.
    [sensorPCB.kicad_pcb, sensorPCB.kicad_sch]
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2026-07-06 Add Amphenol 20021311-00020T4LF (Minitek127) to mezzanine libraries
    Import the Library Loader part (20-pin 1.27mm board-to-board connector)
    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
    [Mission Pegasus.kicad_pcb, sensorPCB.kicad_pcb, sensorPCB.kicad_sch]
2026-07-06 Add Samtec FTSH-110-01-F-D-RA header to main board libraries
    into the main board's SamacSys_Parts library: footprint, 3D model, and
    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
    [sensorPCB.kicad_pcb]
2026-07-07 Add Samtec FTSH-105-04-L-D-RA and SFMC-105-01-L-D to both boards
    Import two Library Loader parts (a 2x5 1.27mm right-angle header and its
    mating 2x5 socket strip) into the SamacSys_Parts library of BOTH the main
    board and the mezzanine board: footprints, 3D models, and symbols
    appended. 3D paths rewritten to ${KIPRJMOD}-relative and each symbol's
    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
    [Mission Pegasus.kicad_sch, PCBAssembly.iam, PCBboard.ipt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]
2026-07-07 Attach Raspberry Pi Zero 2 W 3D model to RPi footprint
    Add the mechanical STEP model of the Raspberry Pi Zero 2 W board
    (RaspberryPi_Zero_2W.step, from the downloaded SolidWorks CAD) to
    main-board 3dmodels, and reference it from the RASPBERRYPI-ZERO_RPI-ZERO
    footprint via a ${KIPRJMOD}-relative path. Offset/rotation set to zero as
    a starting point - needs alignment tuning in KiCad's 3D tab.
    [Mission Pegasus.kicad_pcb, Mission Pegasus.kicad_sch, sensorPCB.kicad_pcb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]
2026-07-07 Add J4 and J5 sensor-board connectors (3 parallel positions)
    Add two more FTSH-105-04-L-D-RA connectors (J4, J5) alongside J3 on the
    main board so the 90-degree sensor board can mount in three interchangeable
    positions, wired in parallel to the same nets. Includes associated power
    and decoupling.
    [Mission Pegasus.kicad_sch]
2026-07-08 Add Vishay CRCW06032K20FKEA (2.2k 0603) to mezzanine libraries
    Import the Library Loader part (2.2k ohm 0603 resistor) into the
    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
    [Mission Pegasus.kicad_pcb, Mission Pegasus.kicad_sch]
2026-07-10 Initial sensor board routing
    [sensorPCB.kicad_pcb, sensorPCB.kicad_sch]
2026-07-10 Fixed warnings
    [sensorPCB.kicad_pcb, sensorPCB.kicad_sch]
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2026-07-20 Update larger board design
    [Mission Pegasus.kicad_pcb, Mission Pegasus.kicad_sch, RPI0.kicad_sch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]
2026-07-22 Moved RA connectors back to 16mm away
    [10.ipt, 54548-2271, 22 Pin FPC Connector, Raspberry Pi Zero 2 W.ipt, 7427927161.iam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]
2026-10-04 Update PCB designs, CAD assemblies, analysis and BOM files
    [615Bracket.ipt, AS72651-BLGT.0001.iam, AS72651-BLGT.0001.ipt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]
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
